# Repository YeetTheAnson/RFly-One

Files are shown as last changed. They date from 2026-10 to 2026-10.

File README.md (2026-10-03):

# RFly One

## Introduction
This project was inspired by [adsbee](https://github.com/PantsForBirds/adsbee) and [SoftRF](https://github.com/PantsForBirds/adsbee)!

This is the RFly One! This project was designed to be a fully offline general aviation proximity awareness system. The RFly One includes a custom ADS-B 1090MHz receiver frontend and support for FLARM AIR V7, OGNTP, FANET+ and more protocols, designed to keep pilots or enthusiasts aware of nearby manned or unmanned aerial vehicles without relying on an active internet connection.

The RFly One has a 2.4" TFT display to show nearby air traffic on an offline map (which can be loaded onto the SD card) or used as a flight insturment dashboard. It also has a BMI270 IMU and a MMC5983MA magnetometer to provide accurate heading, combined with an ATGM332D-5N31 GNSS module to show the current location on a map.

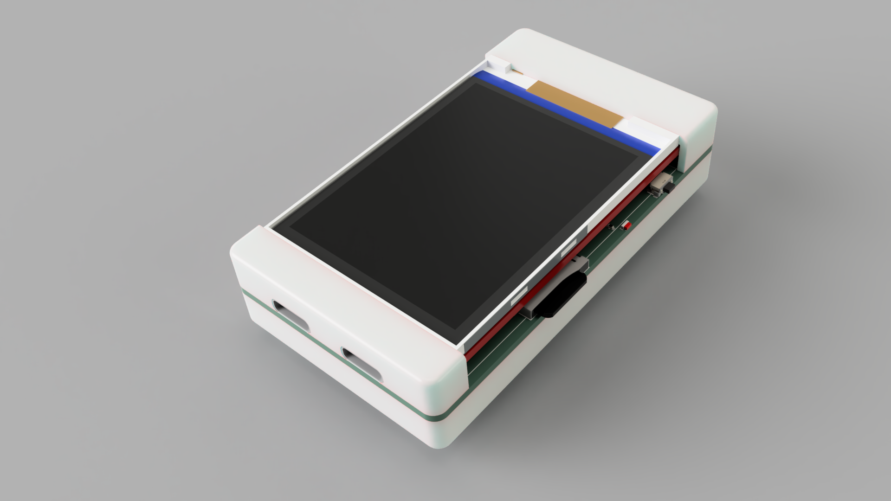
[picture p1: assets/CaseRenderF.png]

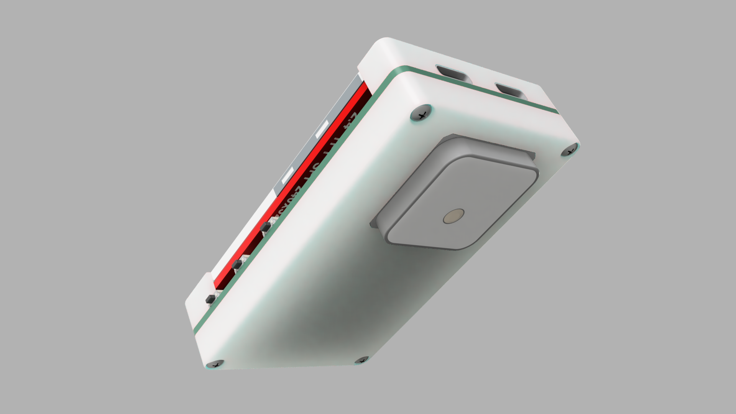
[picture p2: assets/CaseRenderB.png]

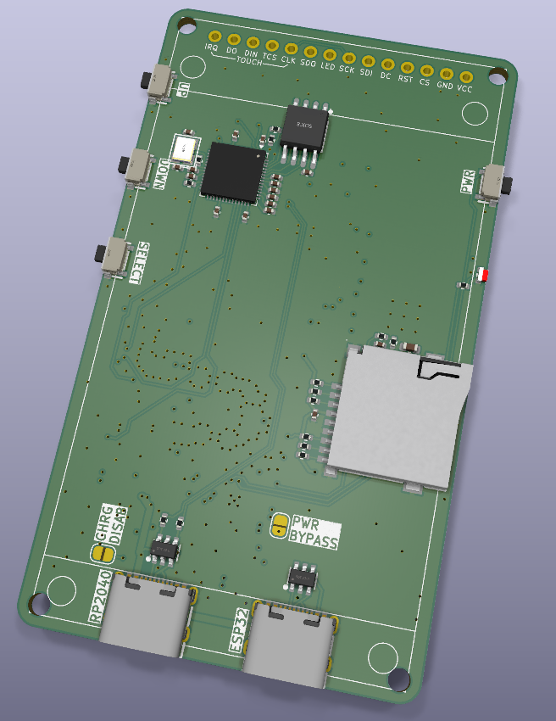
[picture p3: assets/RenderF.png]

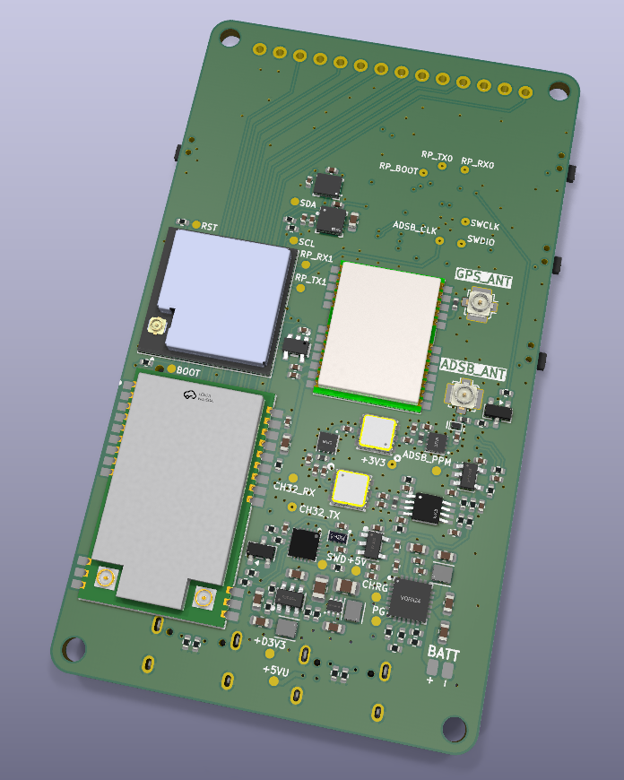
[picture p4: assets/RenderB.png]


## Specifications

### Features
* **Awareness Protocols:** ADS-B, FLARM AIR V7, OGNTP, FANET+, RemoteID
* **Positioning:** GNSS, Gyro, Accelerometer, Magnetometer
* **Storage:** MicroSD Card (For offline maps and flight logging)
* **Charging:** 2A Max

### Hardware
* **Main Processor** ESP32-S3
* **ADS-B Decoder:** RP2040
* **Button/Power Control:** CH32V003
* **GNSS:** ATGM332D-5N31
* **IMU:** BMI270
* **Magnetometer:** MMC5983MA
* **LoRa Radio:** E80-900M2212S (LR2021)
* **Display:** 2.4" TFT

## Pinout
| Feature | Pin name | ESP32 Pin | Description |
|---|---|---|---|
| **LCD** | `LCD_MOSI` | `GPIO 42` | SPI MOSI |
| | `LCD_MISO` | `GPIO 39` | SPI MISO |
| | `LCD_SCK` | `GPIO 41` | SPI Clock |
| | `LCD_CS` | `GPIO 44` | SPI Chip Select |
| | `LCD_LED` | `GPIO 40` | Backlight Control |
| | `LCD_CMD` | `GPIO 43` | LCD Command |
| **IMU** | `SDA` | `GPIO 36` | I2C Data |
| | `SCL` | `GPIO 35` | I2C Clock |
| **SD Card** | `SDIO_DAT0` | `GPIO 9` | Data 0 |
| | `SDIO_DAT1` | `GPIO 8` | Data 1 |
| | `SDIO_DAT2` | `GPIO 12` | Data 2 |
| | `SDIO_DAT3` | `GPIO 13` | Data 3 |
| | `SDIO_CMD` | `GPIO 11` | SD Command |
| | `SDIO_CD` | `GPIO 7` | SD Detect |
| | `SDIO_CLK` | `GPIO 10` | SD Clock |
| **LoRa Radio** | `LORA_MOSI` | `GPIO 2` | SPI MOSI |
| | `LORA_MISO` | `GPIO 1` | SPI MISO |
| | `LORA_SCK` | `GPIO 4` | SPI Clock |
| | `LORA_CE` | `GPIO 5` | SPI Chip Enable |
| | `LORA_BUSY` | `GPIO 16` | Radio Busy |
| **GNSS Module** | `GNSS_TX` | `GPIO 15` | UART RX |
| | `GNSS_RX` | `GPIO 14` | UART TX |
| | `PPS` | `GPIO 17` | GNSS Time |
| **Button/Power Control** | `CH32_TX` | `GPIO 21` | UART RX |
| | `CH32_RX` | `GPIO 18` | UART TX |
| | `BATT_ADC` | `GPIO 6` | ADC1 |
| **ADSB Decoder** | `RP_TX` | `GPIO 47` | UART RX |
| | `RP_RX` | `GPIO 48` | UART TX |
| | `ADSB_CLK` | `GPIO 34` | Extracted Clock From ADSB Signal |

----

## Hardware Overview
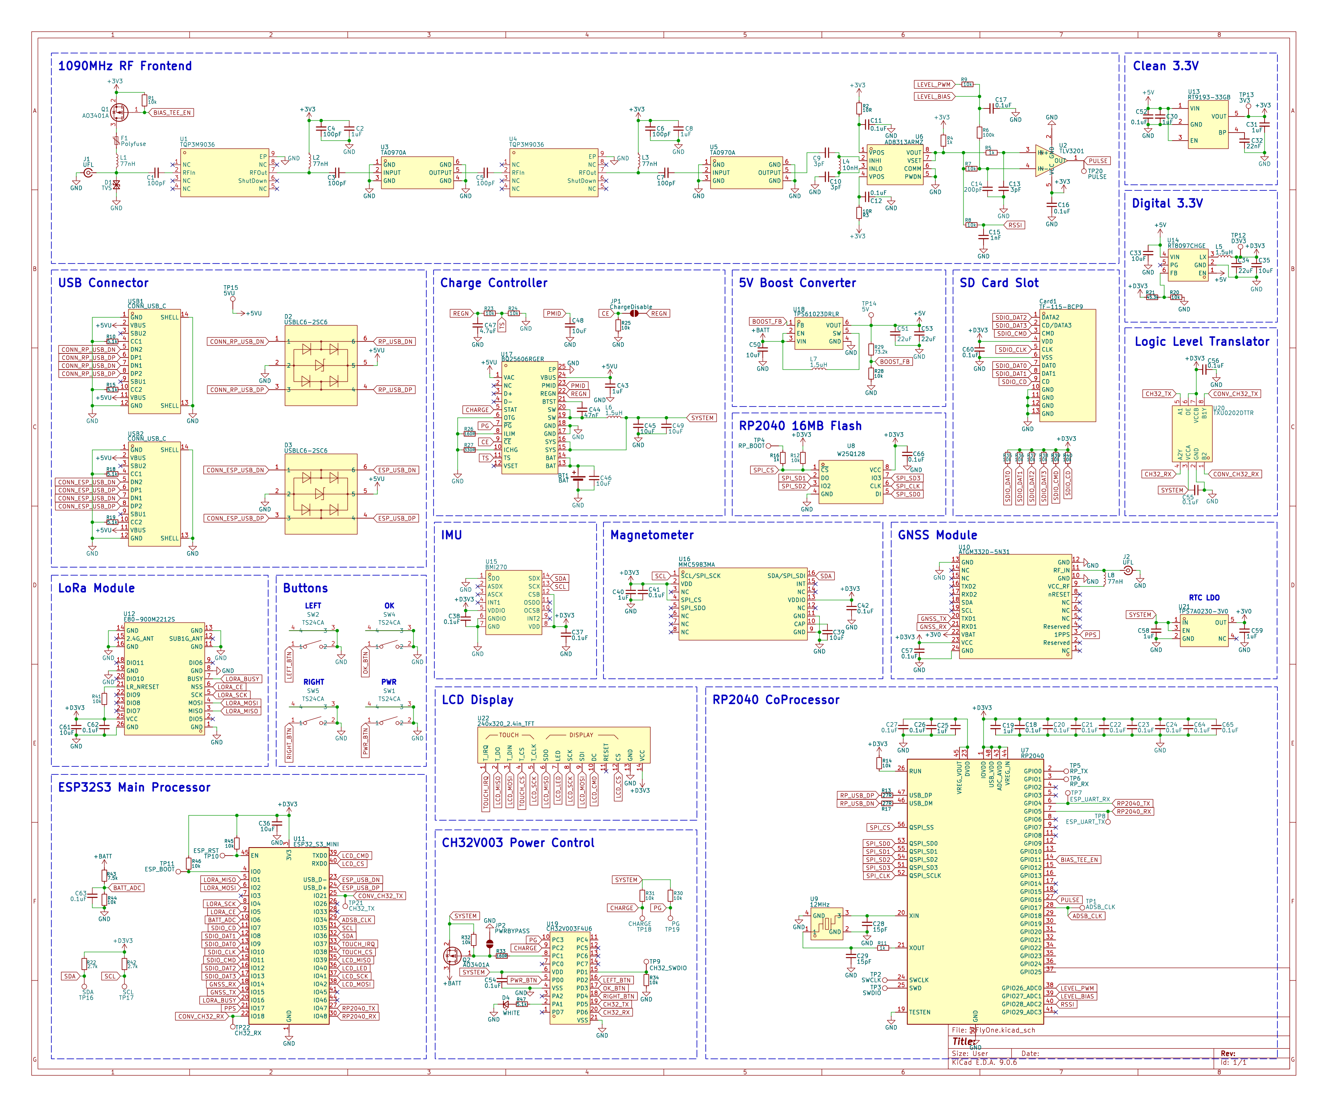
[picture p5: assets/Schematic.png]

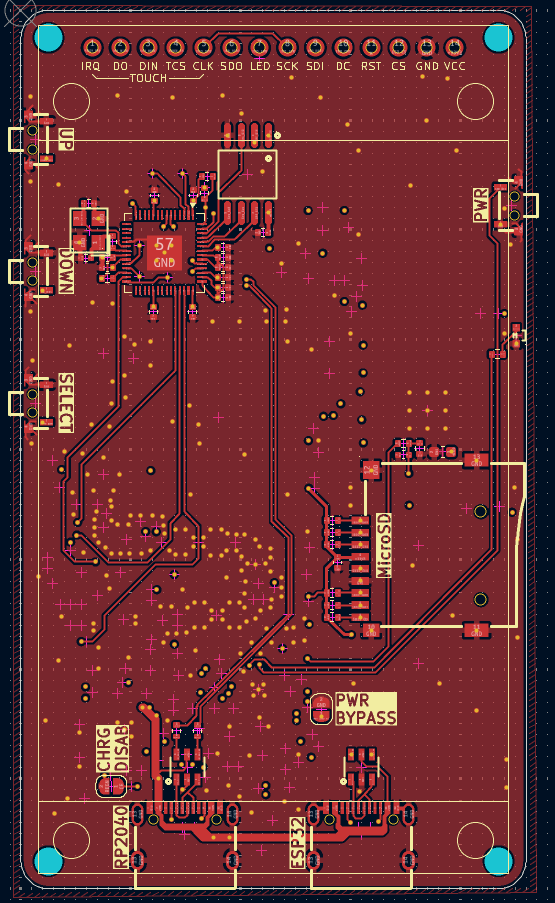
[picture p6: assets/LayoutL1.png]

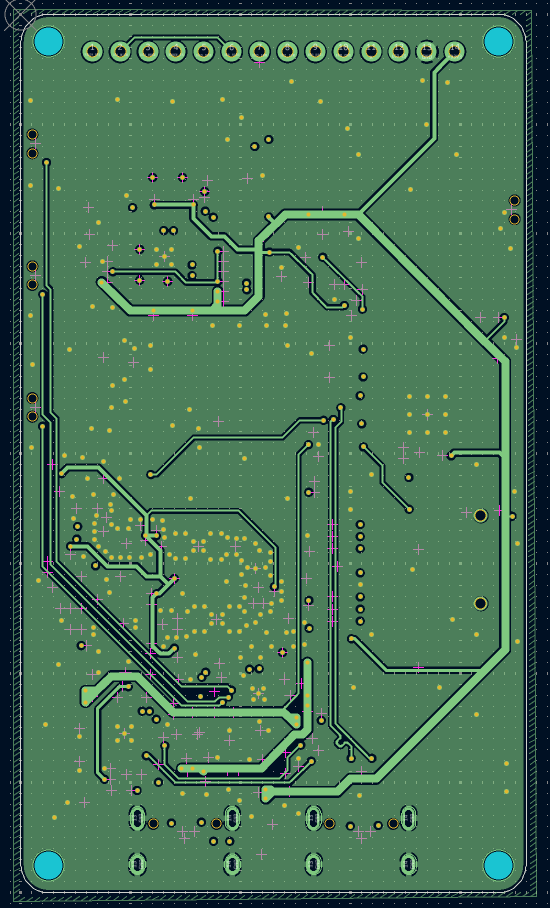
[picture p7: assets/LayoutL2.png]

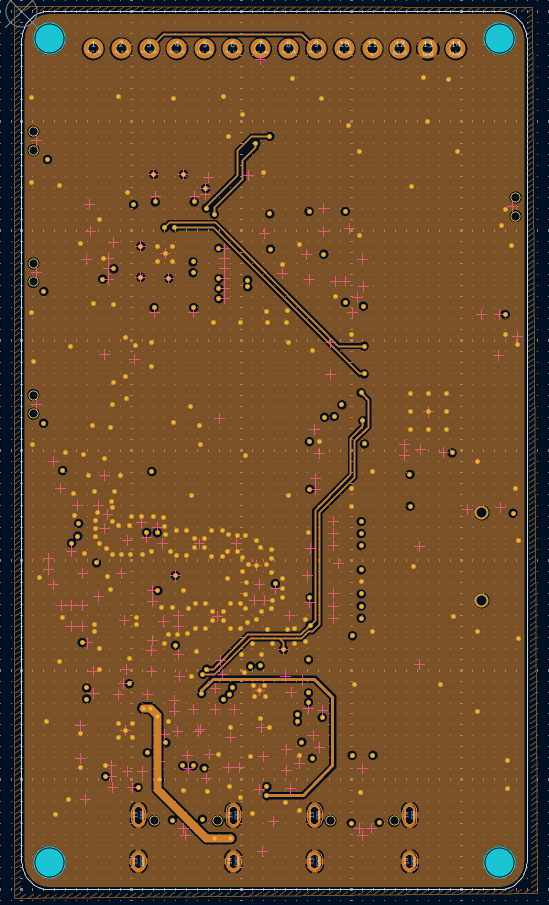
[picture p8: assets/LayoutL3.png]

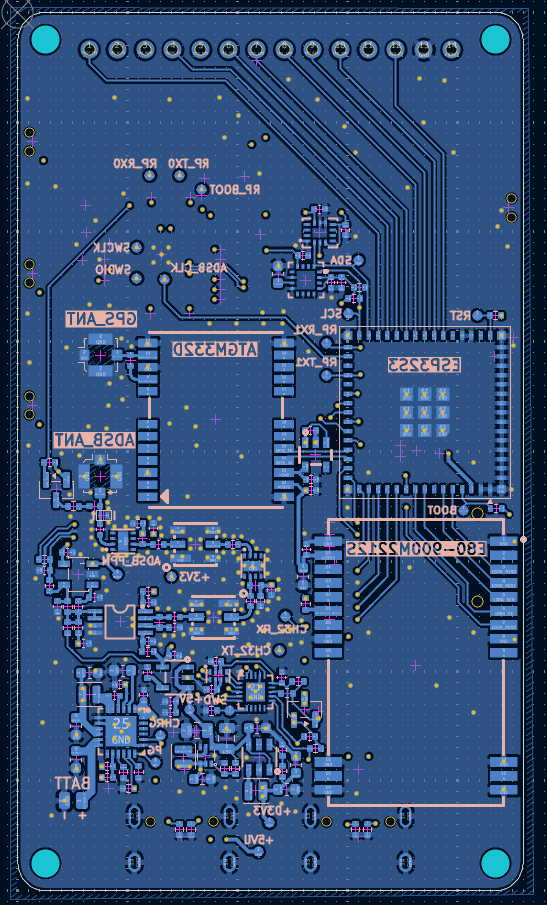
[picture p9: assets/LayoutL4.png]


----

## Firmware

### Building the RP2040 Firmware
1. Clone [this repository](https://github.com/YeetTheAnson/RFly-One) and enter the directory `cd RFly-One`
2. Open the `/firmware/source/rp2040.ino` file in ArduinoIDE
3. Paste `https://github.com/earlephilhower/arduino-pico/releases/download/global/package_rp2040_index.json` into `File > Preferences > Additional boards manager URLs`
4. Go to boards manager and install `Raspberry Pi Pico/RP2040/RP2350` by Earle F. Philhower, III
5. Click the upload button or `Sketch > Export Compiled Binary`

### Building the CH32V003 Firmware
1. Clone [this repository](https://github.com/YeetTheAnson/RFly-One) and enter the directory `cd RFly-One`
2. Open the `/firmware/source/ch32v003.ino` file in ArduinoIDE
3. Paste `https://alexandermandera.github.io/arduino-wch32v003/package_ch32v003_index.json` into `File > Preferences > Additional boards manager URLs`
4. Go to boards manager and install `WCH Boards` by Alexander Mandera
5. Click the upload button or `Sketch > Export Compiled Binary`

### Building the ESP32S3 Firmware
1. Clone [this repository](https://github.com/YeetTheAnson/RFly-One) and enter the directory `cd RFly-One`
2. Open the `/firmware/source/esp32.ino` file in ArduinoIDE
3. Paste `https://espressif.github.io/arduino-esp32/package_esp32_index.json` into `File > Preferences > Additional boards manager URLs`
4. Go to boards manager and install `ESP32` by Espressif
5. Click the upload button or `Sketch > Export Compiled Binary`

----

## Assembly

### Component List
* **Shell:**
    - [TopCase1.stl](https://github.com/YeetTheAnson/RFly-One/tree/main/production/3dPrint/TopCase1.stl)
    - [TopCase2.stl](https://github.com/YeetTheAnson/RFly-One/tree/main/production/3dPrint/TopCase2.stl)
    - [BottomCase.stl](https://github.com/YeetTheAnson/RFly-One/tree/main/production/3dPrint/BottomCase.stl)
* **PCB:**
    - [RFlyOne.zip](https://github.com/YeetTheAnson/RFly-One/tree/main/production/PCB/RFlyOne.zip)  
* **Fasteners:** 4x M2 10mm Self Tapping Screws
* **Battery:** Generic 500mAh LiPo battery (Size of battery is your choice)
* **SD Card:** Generic micro SD Card
* **Antennae:**
    - 2x 2400MHz FPC Antenna
    - 1x 1090MHz FPC Antenna
    - 1x 900MHz FPC Antenna
    - 1x Active GPS Ceramic Antenna

### Assembly Instructions
1. Slide the 3d printed parts `TopCase1.stl` and `TopCase2.stl` into place underneath the TFT LCD board.

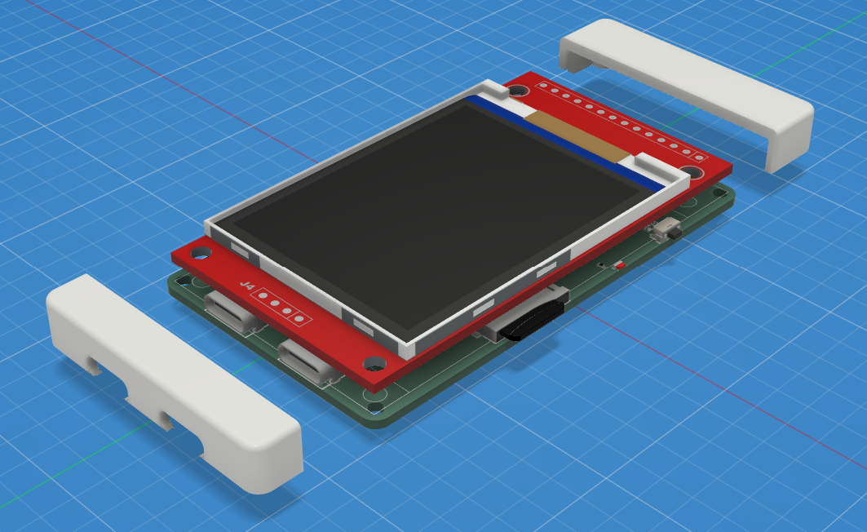
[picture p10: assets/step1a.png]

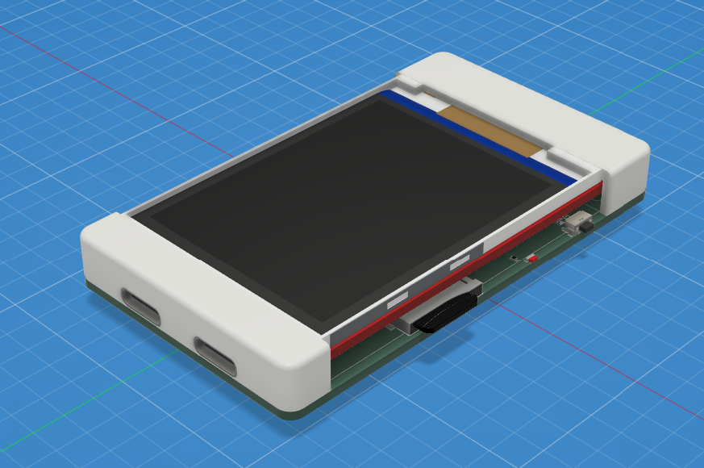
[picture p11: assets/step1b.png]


2. Attach the battery using double sided adhesives and solder the battery cable onto the dedicated pad. Then connect the 2.4GHz WiFi antenna, 2.4GHz LoRa antenna, 1090MHz ADSB antenna and 900MHz LoRa antenna, and secure the FPC antennae to `BottomCase.stl` using double sided adhesives.

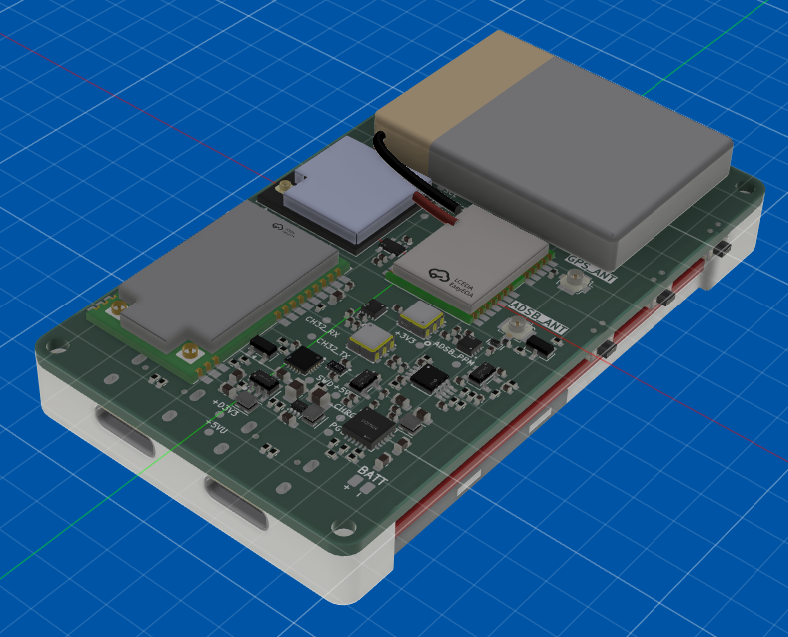
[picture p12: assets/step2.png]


3. Feed the GNSS antenana cable through the `BottomCase.stl` cutout and glue the antenna to the bottom case. Then connect the GNSS antenna connector to the PCB and close the case.

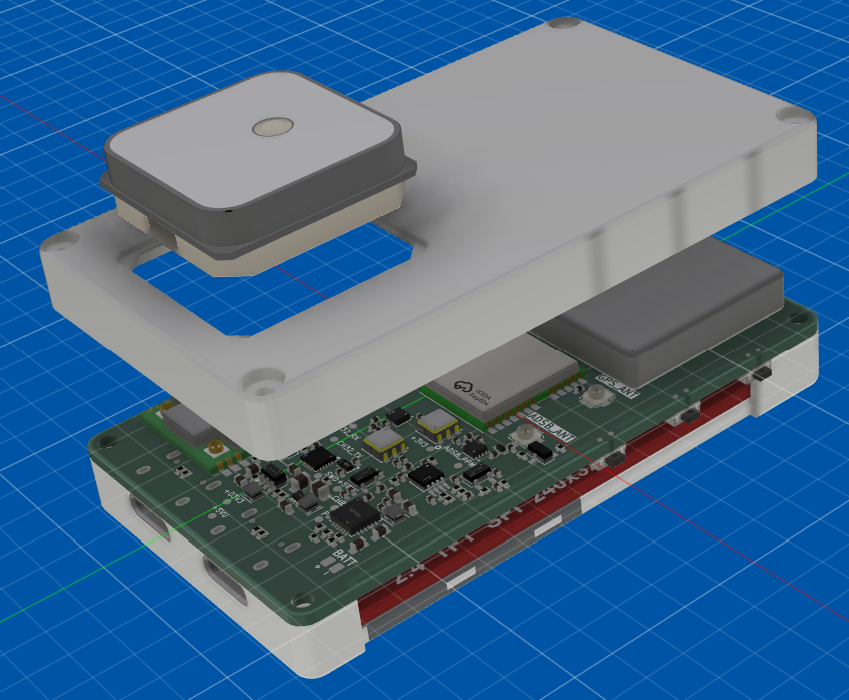
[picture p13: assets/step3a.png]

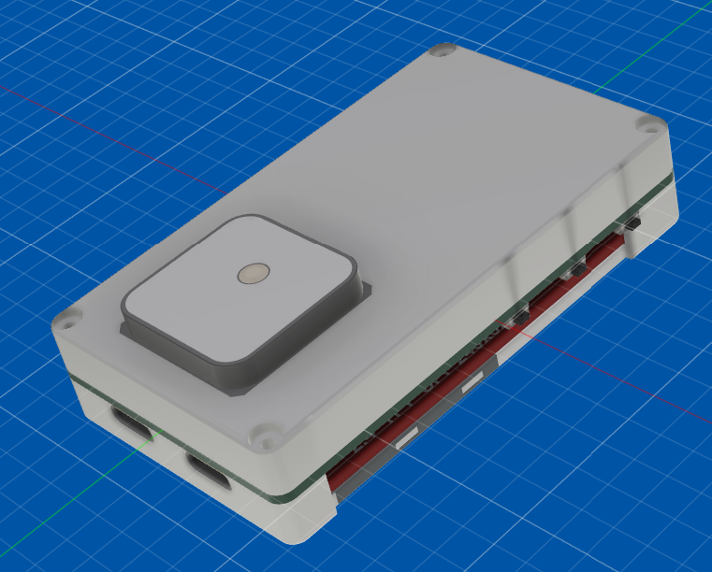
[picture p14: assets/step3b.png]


4. Secure the case using 4x M2 10mm Self Tapping Screws

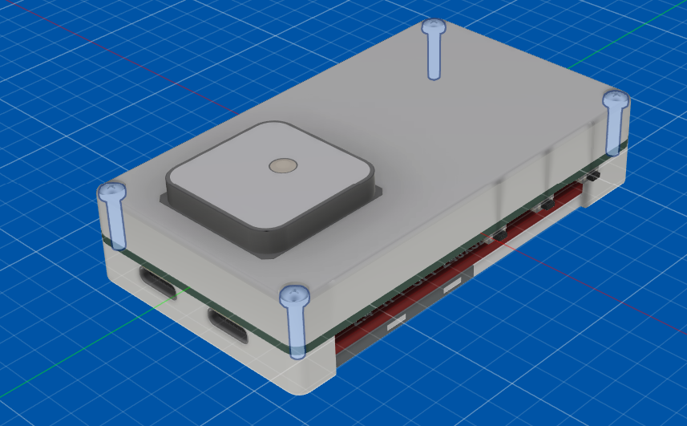
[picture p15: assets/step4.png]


----

## Bill of Material

| Category | Item Name | Description | Link | Vendor | Quantity | Total Price (USD) |
|---|---|---|---|---|---:|---:|
| PCB Components | CL10A106MA8NRNC | 10uF 0603 capacitor | [link](https://www.lcsc.com/product-detail/C96446.html) | LCSC | 20 | 1.52 |
| PCB Components | AO3401A | P channel MOSFET | [link](https://www.lcsc.com/product-detail/C15127.html) | LCSC | 5 | 0.51 |
| PCB Components | GRM1555C1H101JA01D | 100pF 0402 capacitor | [link](https://www.lcsc.com/product-detail/C77177.html) | LCSC | 50 | 0.55 |
| PCB Components | GJM1555C1H3R0BB01D | 3pF 0402 capacitor | [link](https://www.lcsc.com/product-detail/C88891.html) | LCSC | 50 | 0.86 |
| PCB Components | CC0402JRNPO9BN201 | 200pF 0402 capacitor | [link](https://www.lcsc.com/product-detail/C325462.html) | LCSC | 50 | 0.45 |
| PCB Components | CC0402KRX7R9BB102 | 1nF 0402 capacitor | [link](https://www.lcsc.com/product-detail/C106205.html) | LCSC | 100 | 0.23 |
| PCB Components | CC0402JRNPO9BN150 | 15pF 0402 capacitor | [link](https://www.lcsc.com/product-detail/C106997.html) | LCSC | 100 | 0.20 |
| PCB Components | CL21A226MOQNNNE | 22uF 0805 capacitor | [link](https://www.lcsc.com/product-detail/C98190.html) | LCSC | 10 | 1.06 |
| PCB Components | RClamp3361P-ES | 0.25pF DFN1006 TVS diode | [link](https://www.lcsc.com/product-detail/C22464622.html) | LCSC | 5 | 0.60 |
| PCB Components | 0402L020/6SR | 200mA 0402 PTC Fuse | [link](https://www.lcsc.com/product-detail/C53280164.html) | LCSC | 10 | 0.71 |
| PCB Components | LQW15CN77NJ10D | 77nH 0402 inductor | [link](https://www.lcsc.com/product-detail/C668466.html) | LCSC | 10 | 0.88 |
| PCB Components | LQG15HS10NJ02D | 10nH 0402 inductor | [link](https://www.lcsc.com/product-detail/C77103.html) | LCSC | 50 | 0.93 |
| PCB Components | RC0402FR-0727RL | 27R 0402 resistor | [link](https://www.lcsc.com/product-detail/C138021.html) | LCSC | 100 | 0.40 |
| PCB Components | RC0402FR-0745K3L | 45.3k 0402 resistor | [link](https://www.lcsc.com/product-detail/C137977.html) | LCSC | 100 | 0.17 |
| PCB Components | FRC0402F2701TS | 2.7k 0402 resistor | [link](https://www.lcsc.com/product-detail/C2909332.html) | LCSC | 100 | 0.19 |
| PCB Components | FRC0402F1600TS | 160R 0402 resistor | [link](https://www.lcsc.com/product-detail/C2933075.html) | LCSC | 100 | 0.18 |
| PCB Components | FRC0402F3300TS | 330R 0402 resistor | [link](https://www.lcsc.com/product-detail/C2930002.html) | LCSC | 100 | 0.22 |
| PCB Components | FRC0402F7322TS | 73.2k 0402 resistor | [link](https://www.lcsc.com/product-detail/C2998163.html) | LCSC | 100 | 0.19 |
| PCB Components | 0402WGF7501TCE | 7.5k 0402 resistor | [link](https://www.lcsc.com/product-detail/C25918.html) | LCSC | 100 | 0.22 |
| PCB Components | ABM8-272-T3 | 12MHz 10pF 3225 crystal | [link](https://www.lcsc.com/product-detail/C20625731.html) | LCSC | 1 | 0.63 |
| PCB Components | ATGM332D-5N31 | GNSS module | [link](https://www.lcsc.com/product-detail/C128659.html) | LCSC | 1 | 3.58 |
| PCB Components | BMI270 | IMU | [link](https://www.lcsc.com/product-detail/C2836813.html) | LCSC | 2 | 5.75 |
| PCB Components | BQ25606RGER | Battery charge controller | [link](https://www.lcsc.com/product-detail/C374063.html) | LCSC | 1 | 1.64 |
| PCB Components | MMC5983MA | Magnetometer | [link](https://www.lcsc.com/product-detail/C404329.html) | LCSC | 1 | 2.28 |
| PCB Components | RT9193-33GB | 3.3V LDO regulator | [link](https://www.lcsc.com/product-detail/C15651.html) | LCSC | 5 | 0.69 |
| PCB Components | TA0970A | 1090MHz SAW filter | [link](https://www.lcsc.com/product-detail/C7115531.html) | LCSC | 2 | 3.09 |
| PCB Components | TLV3201AIDBVR | Comparator | [link](https://www.lcsc.com/product-detail/C105188.html) | LCSC | 1 | 0.98 |
| PCB Components | TPS61023DRLR | Boost converter | [link](https://www.lcsc.com/product-detail/C919459.html) | LCSC | 5 | 1.24 |
| PCB Components | TPS7A0230PDBVR | ULC 3V LDO regulator | [link](https://www.lcsc.com/product-detail/C3747031.html) | LCSC | 1 | 0.45 |
| PCB Components | TQP3M9036 | LNA | [link](https://www.lcsc.com/product-detail/C920261.html) | LCSC | 2 | 6.29 |
| PCB Components | TXU0202DTTR | Logic level translator | [link](https://www.lcsc.com/product-detail/C18197534.html) | LCSC | 2 | 1.62 |
| PCB Components | W25Q128JVSIQ | 128Mb 16MB NOR flash | [link](https://www.lcsc.com/product-detail/C97521.html) | LCSC | 1 | 2.58 |
| PCB Components | ESP32-S3-MINI-1U-N4R2 | Main processor | [link](https://www.lcsc.com/product-detail/C22356044.html) | LCSC | 1 | 4.61 |
| PCB Components | RP2040 | ADSB decoder coprocessor | [link](https://www.lcsc.com/product-detail/C2040.html) | LCSC | 1 | 1.00 |
| PCB Components | LCSC Shipping | 4PX | - | LCSC | 1 | 4.71 |
| PCB | PCB | 4 layer bare PCB | - | JLCPCB | 1 | 8.00 |
| PCB | JLCPCB Shipping | E-POST | - | JLCPCB | 1 | 5.78 |
| PCB Components | E80-900M2213S | LR2021 LoRA module | [link](https://www.aliexpress.com/item/1005012863308600.html) | AliExpress | 1 | 8.69 |
| PCB Components | AD8313ARMZ | RF logarithmic power detector | [link](https://www.aliexpress.com/item/1005009749065916.html) | AliExpress | 1 | 3.31 |
| PCB Components | AliExpress Shipping | AliExpress Shipping | - | AliExpress | 1 | 5.79 |
| Parts | 2.4" TFT LCD | 2.4" TFT LCD | [link](https://shopee.com.my/TFT-Display-0.96-1.3-1.44-1.77-1.8-2.4-2.8-inch-IPS-7P-SPI-HD-65K-TFT-Full-Color-LCD-Module-ST7735-Drive-IC-80*160-For-Arduino-i.299149454.2147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) | Shopee | 1 | 4.35 |
| Parts | UWB 700-2700MHz antenna large | For 1090MHz ADSB receiver | [link](https://shopee.com.my/Gsm-3G-4G-LTE-5G-nb-iot-iot-Module-Signal-Enhancement-FPC-PCB-Built-in-Patch-Antenna-i.419312080.27871596372) | Shopee | 1 | 0.70 |
| Parts | UWB 700-2700MHz antenna small | For 900MHz LoRa transceiver | [link](https://shopee.com.my/Gsm-3G-4G-LTE-5G-nb-iot-iot-Module-Signal-Enhancement-FPC-PCB-Built-in-Patch-Antenna-i.419312080.27871596373) | Shopee | 1 | 0.65 |
| Parts | 2.4GHz antenna | For ESP32 WiFi/BT and LoRa | [link](https://shopee.com.my/2.4g-5g-5.8g-Dual-Band-Antenna-Built-in-FPC-Soft-Board-Antenna-wifi-Bluetooth-PCB-Patch-ipex-Antenna-i.419312080.27171149912) | Shopee | 2 | 0.95 |
| Parts | Shopee Shipping | SPX Express | - | Shopee | 2 | 2.60 |

- **PCB Components Total:** $69.00
- **PCB Total:** $13.78
- **Parts Total:** $9.25
### **Grand Total:** $92.03

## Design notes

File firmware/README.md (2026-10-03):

> [!CAUTION]
> The current firmware is for validation only, and cannnot decode ADS-B signal yet

### ESP32S3
- Initialize 2.4" display and display test results
- Test and return BMI270 IMU & MMC5983 magnetometer raw values
- Test and initialize E80-900M2212S LoRa module
- Test and initialize ATGM332D-5N31 GNSS module
- Test whether CH32V003 can be reached with serial loopback
- Test whether RP2040 can be reached with serial loopback
- Measure frequency of RP2040 ADS-B extracted clock
- Test if SD card can be detected and accessed

### RP2040
- Extract and output a clock signal from ADSB PPM signal with manchester encoding
- Relay serial data

### Ch32V003
- Blink LED
- Power button toggle power on and off to the rest of the system
- Relay serial data
- Send button state over serial

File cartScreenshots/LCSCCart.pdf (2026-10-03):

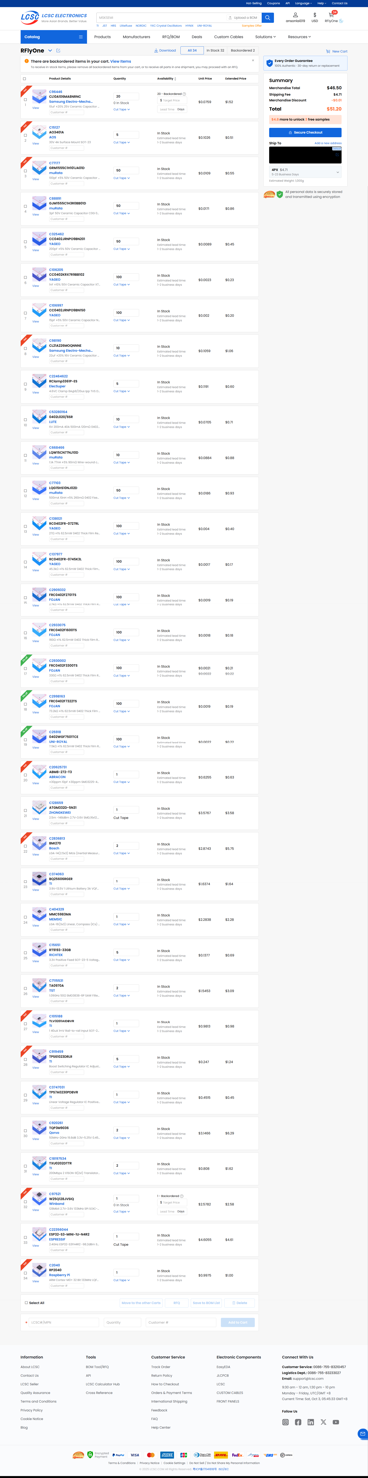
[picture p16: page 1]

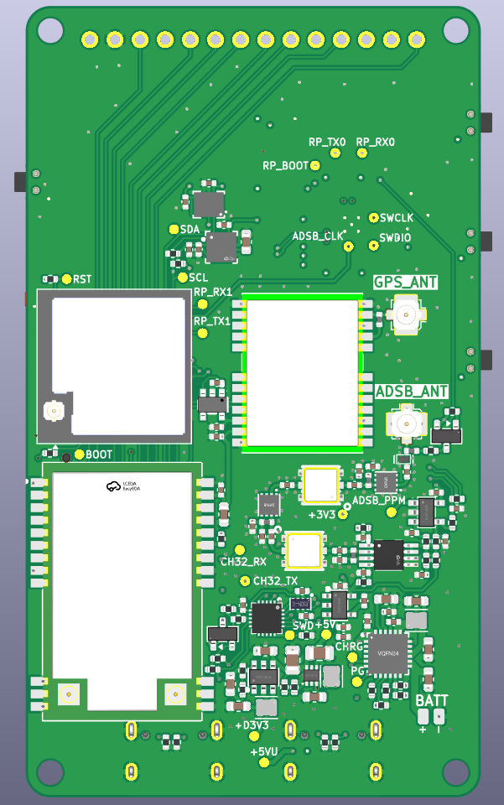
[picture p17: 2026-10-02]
assets/FlatRenderB.png

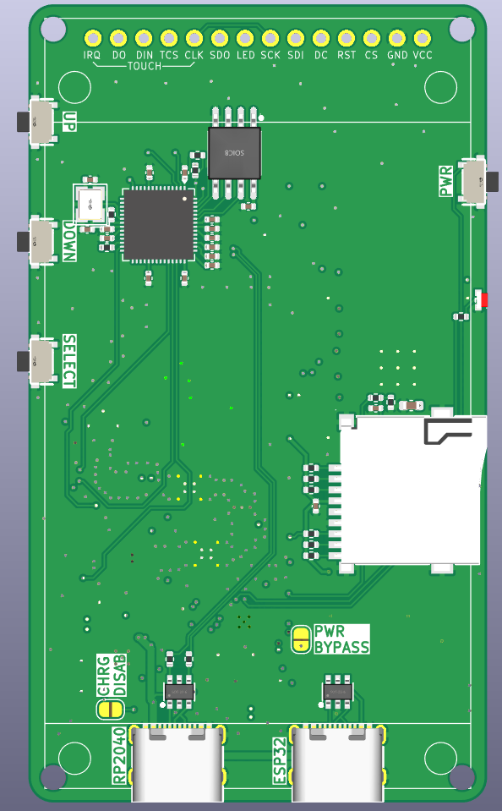
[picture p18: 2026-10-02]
assets/FlatRenderF.png

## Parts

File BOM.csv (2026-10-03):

Category | Item Name | Description | Link | Vendor | Quantity | Total Price (USD)
PCB Components | CL10A106MA8NRNC | 10uF 0603 capacitor | https://www.lcsc.com/product-detail/C96446.html | LCSC | 20 | 1.52
PCB Components | AO3401A | P channel MOSFET | https://www.lcsc.com/product-detail/C15127.html | LCSC | 5 | 0.51
PCB Components | GRM1555C1H101JA01D | 100pF 0402 capacitor | https://www.lcsc.com/product-detail/C77177.html | LCSC | 50 | 0.55
PCB Components | GJM1555C1H3R0BB01D | 3pF 0402 capacitor | https://www.lcsc.com/product-detail/C88891.html | LCSC | 50 | 0.86
PCB Components | CC0402JRNPO9BN201 | 200pF 0402 capacitor | https://www.lcsc.com/product-detail/C325462.html | LCSC | 50 | 0.45
PCB Components | CC0402KRX7R9BB102 | 1nF 0402 capacitor | https://www.lcsc.com/product-detail/C106205.html | LCSC | 100 | 0.23
PCB Components | CC0402JRNPO9BN150 | 15pF 0402 capacitor | https://www.lcsc.com/product-detail/C106997.html | LCSC | 100 | 0.20
PCB Components | CL21A226MOQNNNE | 22uF 0805 capacitor | https://www.lcsc.com/product-detail/C98190.html | LCSC | 10 | 1.06
PCB Components | RClamp3361P-ES | 0.25pF DFN1006 TVS diode | https://www.lcsc.com/product-detail/C22464622.html | LCSC | 5 | 0.60
PCB Components | 0402L020/6SR | 200mA 0402 PTC Fuse | https://www.lcsc.com/product-detail/C53280164.html | LCSC | 10 | 0.71
PCB Components | LQW15CN77NJ10D | 77nH 0402 inductor | https://www.lcsc.com/product-detail/C668466.html | LCSC | 10 | 0.88
PCB Components | LQG15HS10NJ02D | 10nH 0402 inductor | https://www.lcsc.com/product-detail/C77103.html | LCSC | 50 | 0.93
PCB Components | RC0402FR-0727RL | 27R 0402 resistor | https://www.lcsc.com/product-detail/C138021.html | LCSC | 100 | 0.40
PCB Components | RC0402FR-0745K3L | 45.3k 0402 resistor | https://www.lcsc.com/product-detail/C137977.html | LCSC | 100 | 0.17
PCB Components | FRC0402F2701TS | 2.7k 0402 resistor | https://www.lcsc.com/product-detail/C2909332.html | LCSC | 100 | 0.19
PCB Components | FRC0402F1600TS | 160R 0402 resistor | https://www.lcsc.com/product-detail/C2933075.html | LCSC | 100 | 0.18
PCB Components | FRC0402F3300TS | 330R 0402 resistor | https://www.lcsc.com/product-detail/C2930002.html | LCSC | 100 | 0.22
PCB Components | FRC0402F7322TS | 73.2k 0402 resistor | https://www.lcsc.com/product-detail/C2998163.html | LCSC | 100 | 0.19
PCB Components | 0402WGF7501TCE | 7.5k 0402 resistor | https://www.lcsc.com/product-detail/C25918.html | LCSC | 100 | 0.22
PCB Components | ABM8-272-T3 | 12MHz 10pF 3225 crystal | https://www.lcsc.com/product-detail/C20625731.html | LCSC | 1 | 0.63
PCB Components | ATGM332D-5N31 | GNSS module | https://www.lcsc.com/product-detail/C128659.html | LCSC | 1 | 3.58
PCB Components | BMI270 | IMU | https://www.lcsc.com/product-detail/C2836813.html | LCSC | 2 | 5.75
PCB Components | BQ25606RGER | Battery charge controller | https://www.lcsc.com/product-detail/C374063.html | LCSC | 1 | 1.64
PCB Components | MMC5983MA | Magnetometer | https://www.lcsc.com/product-detail/C404329.html | LCSC | 1 | 2.28
PCB Components | RT9193-33GB | 3.3V LDO regulator | https://www.lcsc.com/product-detail/C15651.html | LCSC | 5 | 0.69
PCB Components | TA0970A | 1090MHz SAW filter | https://www.lcsc.com/product-detail/C7115531.html | LCSC | 2 | 3.09
PCB Components | TLV3201AIDBVR | Comparator | https://www.lcsc.com/product-detail/C105188.html | LCSC | 1 | 0.98
PCB Components | TPS61023DRLR | Boost converter | https://www.lcsc.com/product-detail/C919459.html | LCSC | 5 | 1.24
PCB Components | TPS7A0230PDBVR | ULC 3V LDO regulator | https://www.lcsc.com/product-detail/C3747031.html | LCSC | 1 | 0.45
PCB Components | TQP3M9036 | LNA | https://www.lcsc.com/product-detail/C920261.html | LCSC | 2 | 6.29
PCB Components | TXU0202DTTR | Logic level translator | https://www.lcsc.com/product-detail/C18197534.html | LCSC | 2 | 1.62
PCB Components | W25Q128JVSIQ | 128Mb 16MB NOR flash | https://www.lcsc.com/product-detail/C97521.html | LCSC | 1 | 2.58
PCB Components | ESP32-S3-MINI-1U-N4R2 | Main processor | https://www.lcsc.com/product-detail/C22356044.html | LCSC | 1 | 4.61
PCB Components | RP2040 | ADSB decoder coprocessor | https://www.lcsc.com/product-detail/C2040.html | LCSC | 1 | 1.00
PCB Components | LCSC Shipping | 4PX | - | LCSC | 1 | 4.71
PCB | PCB | 4 layer bare PCB | - | JLCPCB | 1 | 8.00
PCB | JLCPCB Shipping | E-POST | - | JLCPCB | 1 | 5.78
PCB Components | E80-900M2213S | LR2021 LoRA module | https://www.aliexpress.com/item/1005012863308600.html | AliExpress | 1 | 8.69
PCB Components | AD8313ARMZ | RF logarithmic power detector | https://www.aliexpress.com/item/1005009749065916.html | AliExpress | 1 | 3.31
PCB Components | AliExpress Shipping | AliExpress Shipping | - | AliExpress | 1 | 5.79
Parts | 2.4" TFT LCD | 2.4" TFT LCD | https://shopee.com.my/TFT-Display-0.96-1.3-1.44-1.77-1.8-2.4-2.8-inch-IPS-7P-SPI-HD-65K-TFT-Full-Color-LCD-Module-ST7735-Drive-IC-80*160-For-Arduino-i.2991494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 | Shopee | 1 | 4.35
Parts | UWB 700-2700MHz antenna large | For 1090MHz ADSB receiver | https://shopee.com.my/Gsm-3G-4G-LTE-5G-nb-iot-iot-Module-Signal-Enhancement-FPC-PCB-Built-in-Patch-Antenna-i.419312080.27871596372 | Shopee | 1 | 0.70
Parts | UWB 700-2700MHz antenna small | For 900MHz LoRa transceiver | https://shopee.com.my/Gsm-3G-4G-LTE-5G-nb-iot-iot-Module-Signal-Enhancement-FPC-PCB-Built-in-Patch-Antenna-i.419312080.27871596373 | Shopee | 1 | 0.65
Parts | 2.4GHz antenna | For ESP32 WiFi/BT and LoRa | https://shopee.com.my/2.4g-5g-5.8g-Dual-Band-Antenna-Built-in-FPC-Soft-Board-Antenna-wifi-Bluetooth-PCB-Patch-ipex-Antenna-i.419312080.27171149912 | Shopee | 2 | 0.95
Parts | Shopee Shipping | SPX Express | - | Shopee | 2 | 2.60
Grand Total | 92.03

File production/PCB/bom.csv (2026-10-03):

Designator | Footprint | Quantity | Value | LCSC Part #
C1, C3, C4, C5, C6, C7 | 0402 | 6 | 100pF | C77177
C10, C13, C9 | 0402 | 3 | 3pF | C88891
C11, C12, C16, C17, C18, C20, C21, C22, C23, C24, C26, C27, C37, C38, C41, C42, C52, C54, C55, C56, C57, C60, C62, C63, C64, C65, C66 | 0402 | 27 | 0.1uF | C307331
C14 | 0402 | 1 | 200pF | C325462
C15 | 0402 | 1 | 1nF | C106205
C19, C2, C25, C30, C31, C40, C43, C58, C59, C8 | 0402 | 10 | 1uF | C52923
C28, C29 | 0402 | 2 | 15pF | C106997
C32 | 0402 | 1 | 22nF | C1532
C33, C35, C36, C39, C45, C46, C48, C49, C50, C61 | 0603 | 10 | 10uF | C96446
C34 | 0603 | 1 | 22uF | C59461
C44 | 0402 | 1 | 47nF | C272875
C47 | 0402 | 1 | 4.7uF | C23733
C51, C53 | 0805 | 2 | 22uF | C98190
CARD1 | TF-SMD_TF-115-BCP9 | 1 | TF-115-BCP9 | C720505
D1 | DFN-2_L1.0-W0.6-P0.65-BI | 1 | TVS | C22464622
D2, D3 | SOT-23-6_L2.9-W1.6-P0.95-LS2.8-BL | 2 | USBLC6-2SC6 | C7519
D4 | LED-SMD_L1.6-W1.1-R-RD_WHITE | 1 | WHITE | C46635136
F1 | 0402 | 1 | Polyfuse | C53280164
J1, J2 | UFL | 2 | UFL | C5137195
L1, L2, L3, L8 | 0402 | 4 | 77nH | C668466
L4 | 0402 | 1 | 10nH | C77103
L5, L6, L7 | L_Changjiang_FTC201610S | 3 | 1.5uH | C5832343
Q1, Q2 | SOT-23 | 2 | AO3401A | C15127
R1, R12, R14, R20, R23, R24, R25, R28, R30, R31, R32, R34, R35, R36, R37, R38, R39, R40, R41, R44, R45, R46, R7, R8, R9 | 0402 | 25 | 10k | C25744
R10, R15, R18, R19, R47 | 0402 | 5 | 5.1k | C25905
R11, R16, R4, R5 | 0402 | 4 | 1k | C11702
R13, R17 | 0402 | 2 | 27R | C138021
R2, R3 | 0402 | 2 | 10R | C25077
R21 | 0402 | 1 | 45.3k | C137977
R22, R42 | 0402 | 2 | 2.7k | C2909332
R26, R33 | 0402 | 2 | 160R | C2933075
R27 | 0402 | 1 | 330R | C2930002
R29 | 0402 | 1 | 73.2k | C2998163
R43 | 0402 | 1 | 7.5k | C25918
R6 | 0402 | 1 | 100k | C25741
SW1, SW2, SW4, SW5 | SW-SMD_2P-TS24CA | 4 | TS24CA | C393942
U1, U4 | DFN-8_L2.0-W2.0-P0.50-BL-EP | 2 | TQP3M9036 | C920261
U10 | GSM-SMD_ATGM332D-5N31 | 1 | ATGM332D-5N31 | C128659
U11 | ESP32-S2-MINI-1U | 1 | ESP32_S3_MINI | C22356044
U12 | WIRELM-SMD_E80-900M2212S | 1 | E80-900M2212S | C55338904
U13 | SOT-23-5_L3.0-W1.7-P0.95-LS2.8-BL | 1 | RT9193-33GB | C15651
U14 | SOT-23-6_L2.9-W1.6-P0.95-LS2.8-BL | 1 | RT8097CHGE | C3031673
U15 | LGA-14_L3.0-W2.5-P0.50-BR | 1 | BMI270 | C2836813
U16 | LGA-16_L3.0-W3.0-P0.50-BL_SQ | 1 | MMC5983MA | C404329
U17 | VQFN-24_L4.0-W4.0-P0.50-TL-EP2.8 | 1 | BQ25606RGER | C374063
U18 | SOT-563_L1.6-W1.2-P0.50-LS1.6-BR | 1 | TPS61023DRLR | C919459
U19 | QFN-20_L3.0-W3.0-P0.40-TL-EP1.7 | 1 | CH32V003F4U6 | C5299908
U2 | SOT-23-5_L3.0-W1.7-P0.95-LS2.8-BR | 1 | TLV3201 | C105188
U20 | XSON-8_L2.0-W1.0-P0.50-BL | 1 | TXU0202DTTR | C18197534
U21 | SOT-23-5_L2.9-W1.6-P0.95-LS2.8-BR | 1 | TPS7A0230-3V0 | C3747031
U3, U5 | FILTER-SMD_6P-L3.8-W3.8-BL | 2 | TA0970A | C7115531
U6 | MSOP-8_L3.0-W3.0-P0.65-LS4.9-BL | 1 | AD8313ARMZ | C578690
U7 | QFN-56-1EP_7x7mm_P0.4mm_EP3.2x3.2mm | 1 | RP2040 | C2040
U8 | SOIC-8_L5.3-W5.3-P1.27-LS8.0-BL | 1 | W25Q128 | C97521
U9 | CRYSTAL-SMD_4P-L3.2-W2.5-BL | 1 | 12MHz | C20625731
USB1, USB2 | USB-C-SMD_TYPE-C-6PIN-2MD-073 | 2 | CONN_USB_C | C2765186

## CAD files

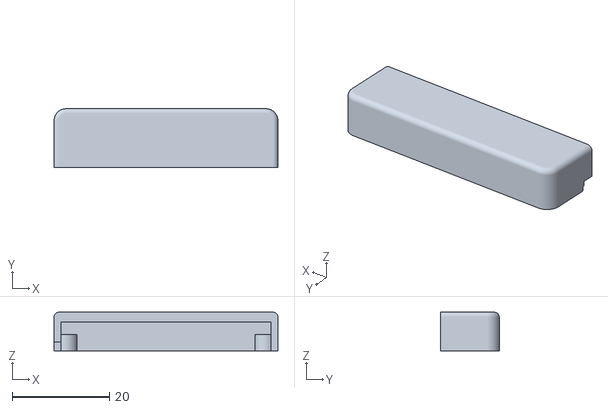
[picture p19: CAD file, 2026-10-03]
production/3dPrint/TopCase2.stl
46.0 x 12.0 x 7.93

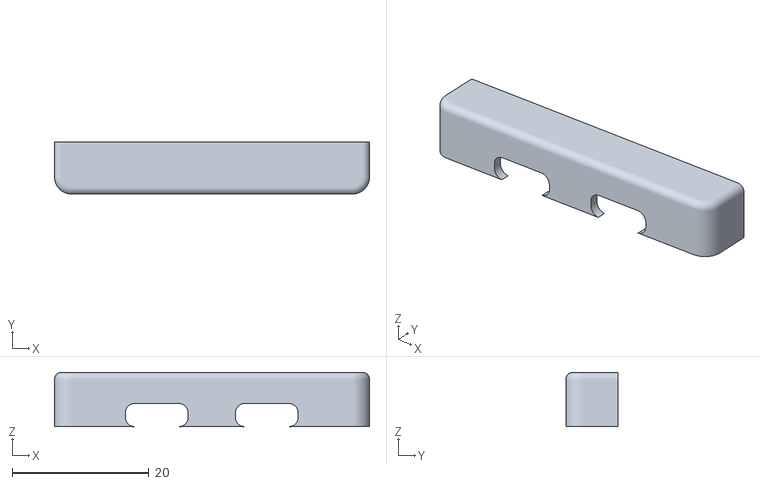
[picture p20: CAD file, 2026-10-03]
production/3dPrint/TopCase1.stl
46.0 x 7.62 x 7.93

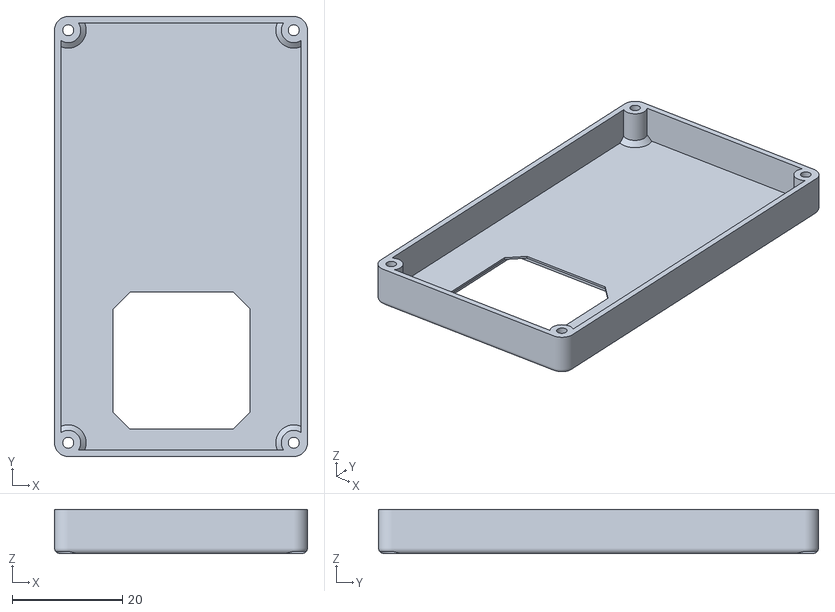
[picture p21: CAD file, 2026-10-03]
production/3dPrint/BottomCase.stl
46.0 x 80.0 x 8.00

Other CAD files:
CAD/Assembled.f3z

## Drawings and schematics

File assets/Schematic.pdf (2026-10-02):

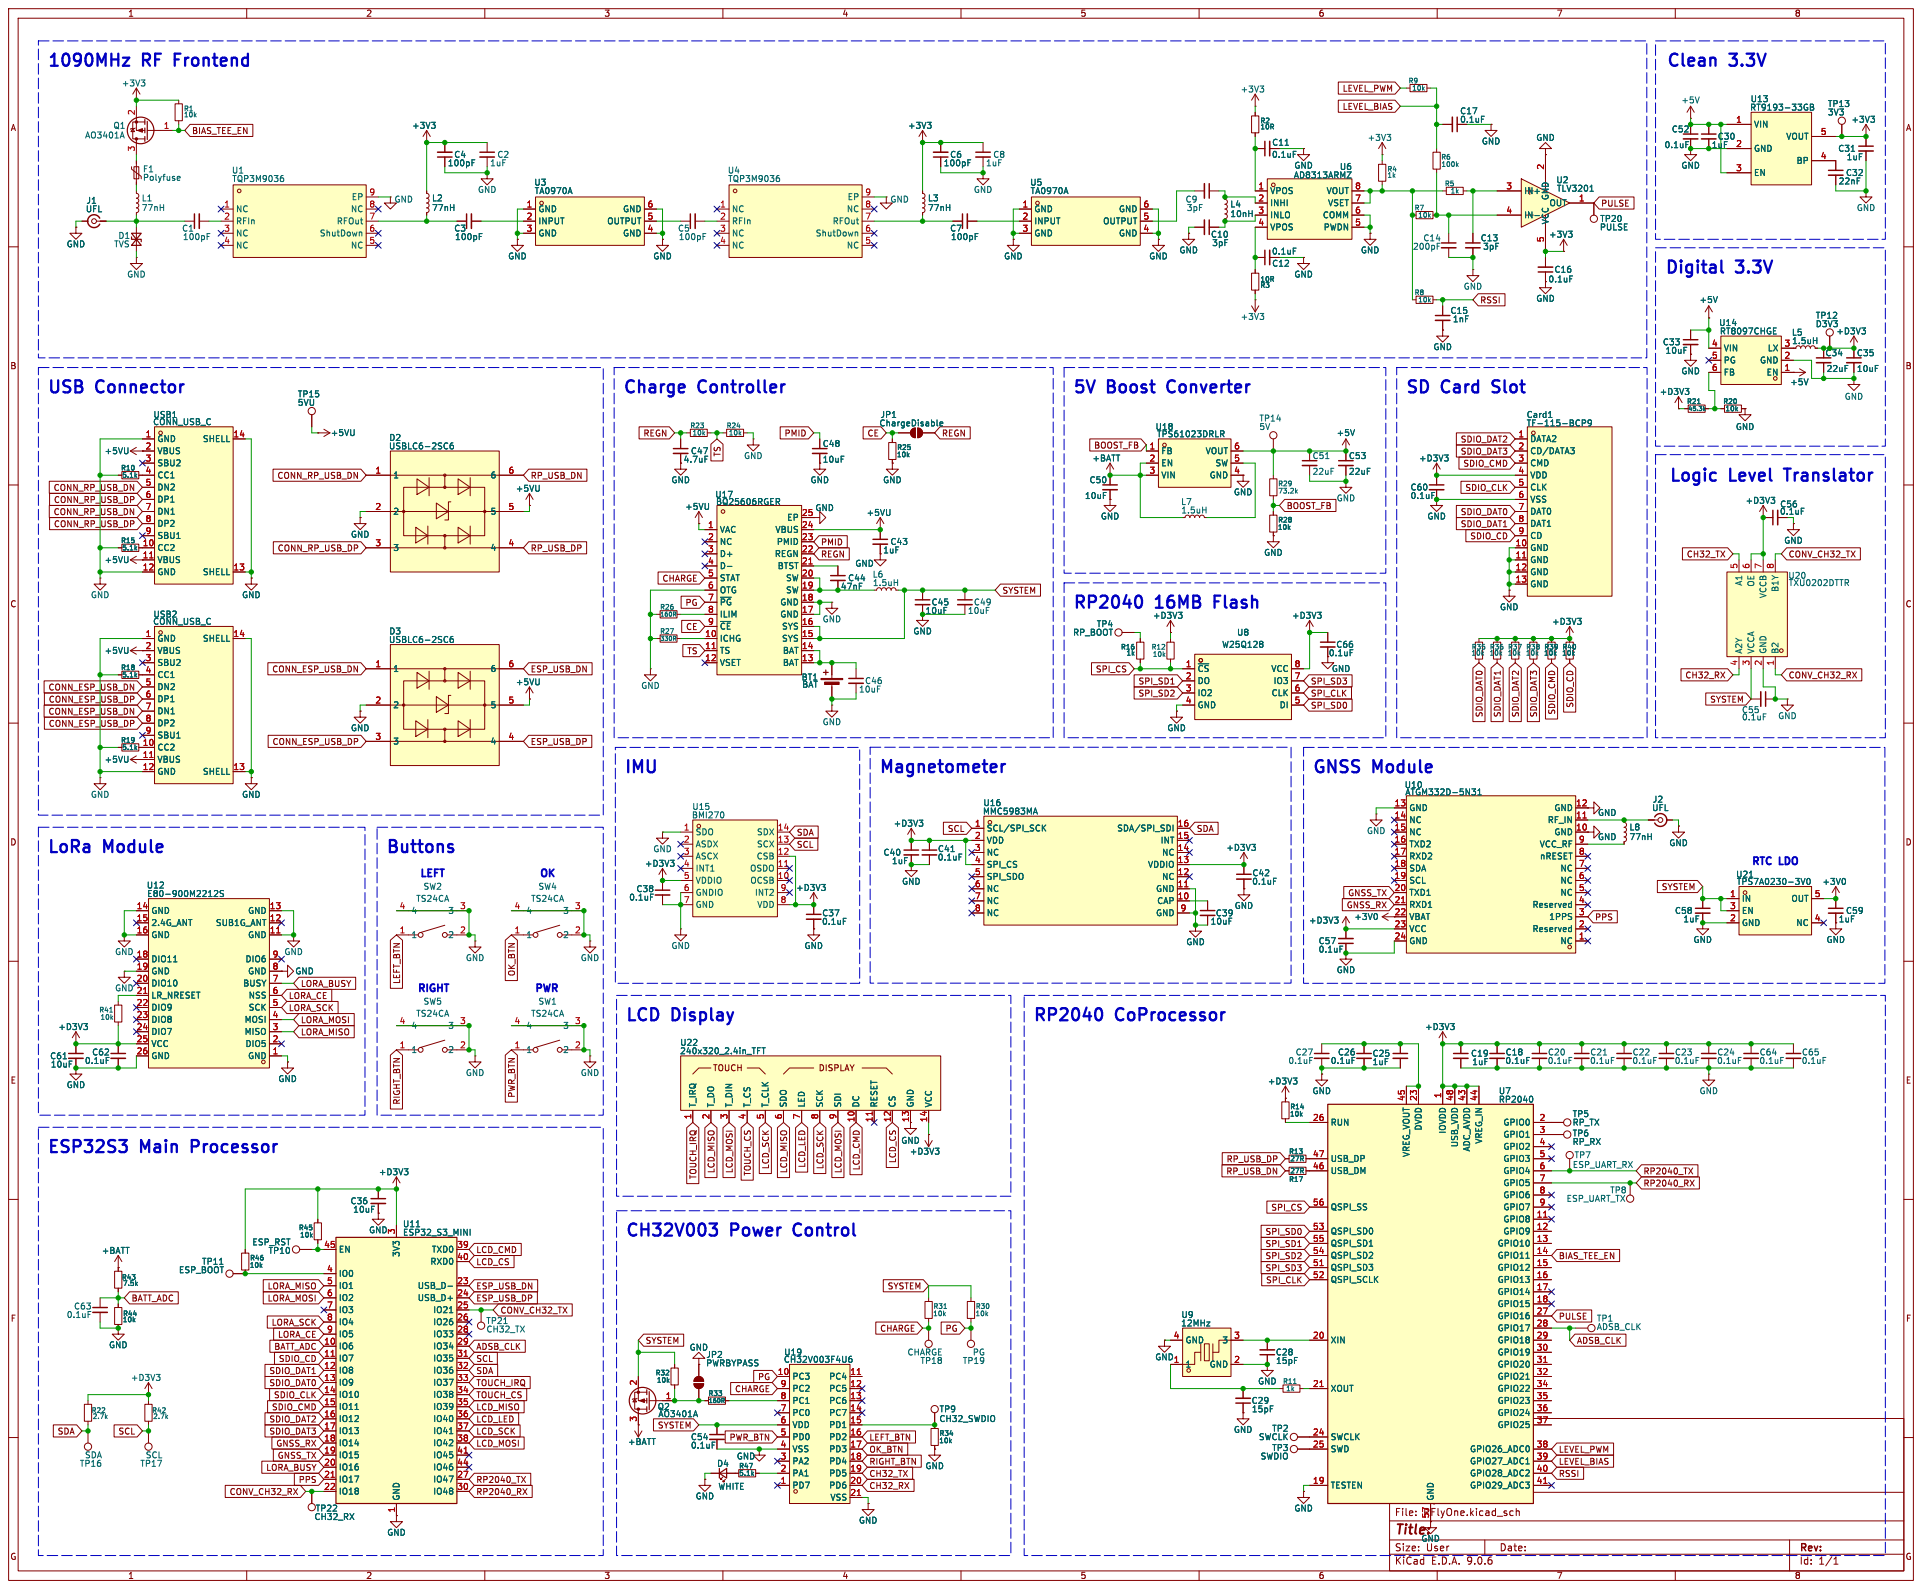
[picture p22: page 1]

2 OUT 1 U2TLV3201 GND GND GND GND

10k +D3V3 DATA2 1 CD/DATA3 2 CMD 3 VDD 4 CLK 5 VSS 6 DAT0 7 DAT1 8 CD 9 GND 10 GND 11 GND 12 GND 13 Card1 TF-115-BCP9 C1

BT1 BAT GND 1 DIO5 2 MISO 3 MOSI 4 SCK 5 NSS 6 BUSY 7 GND 8 DIO6 9 GND 11 GND 13 GND 26 VCC 25 DIO7 24 DIO8 23 DIO9 22

nRESET 8 NC 7 NC 6 NC 5 Reserved 4

8 SDI 9 DC 10 RESET 11 CS 12 GND 13 VCC 14 GND

8 SDI 9 DC 10 RESET 11 CS 12 GND 13 VCC 14 U22
240x320_2.4in_TFT

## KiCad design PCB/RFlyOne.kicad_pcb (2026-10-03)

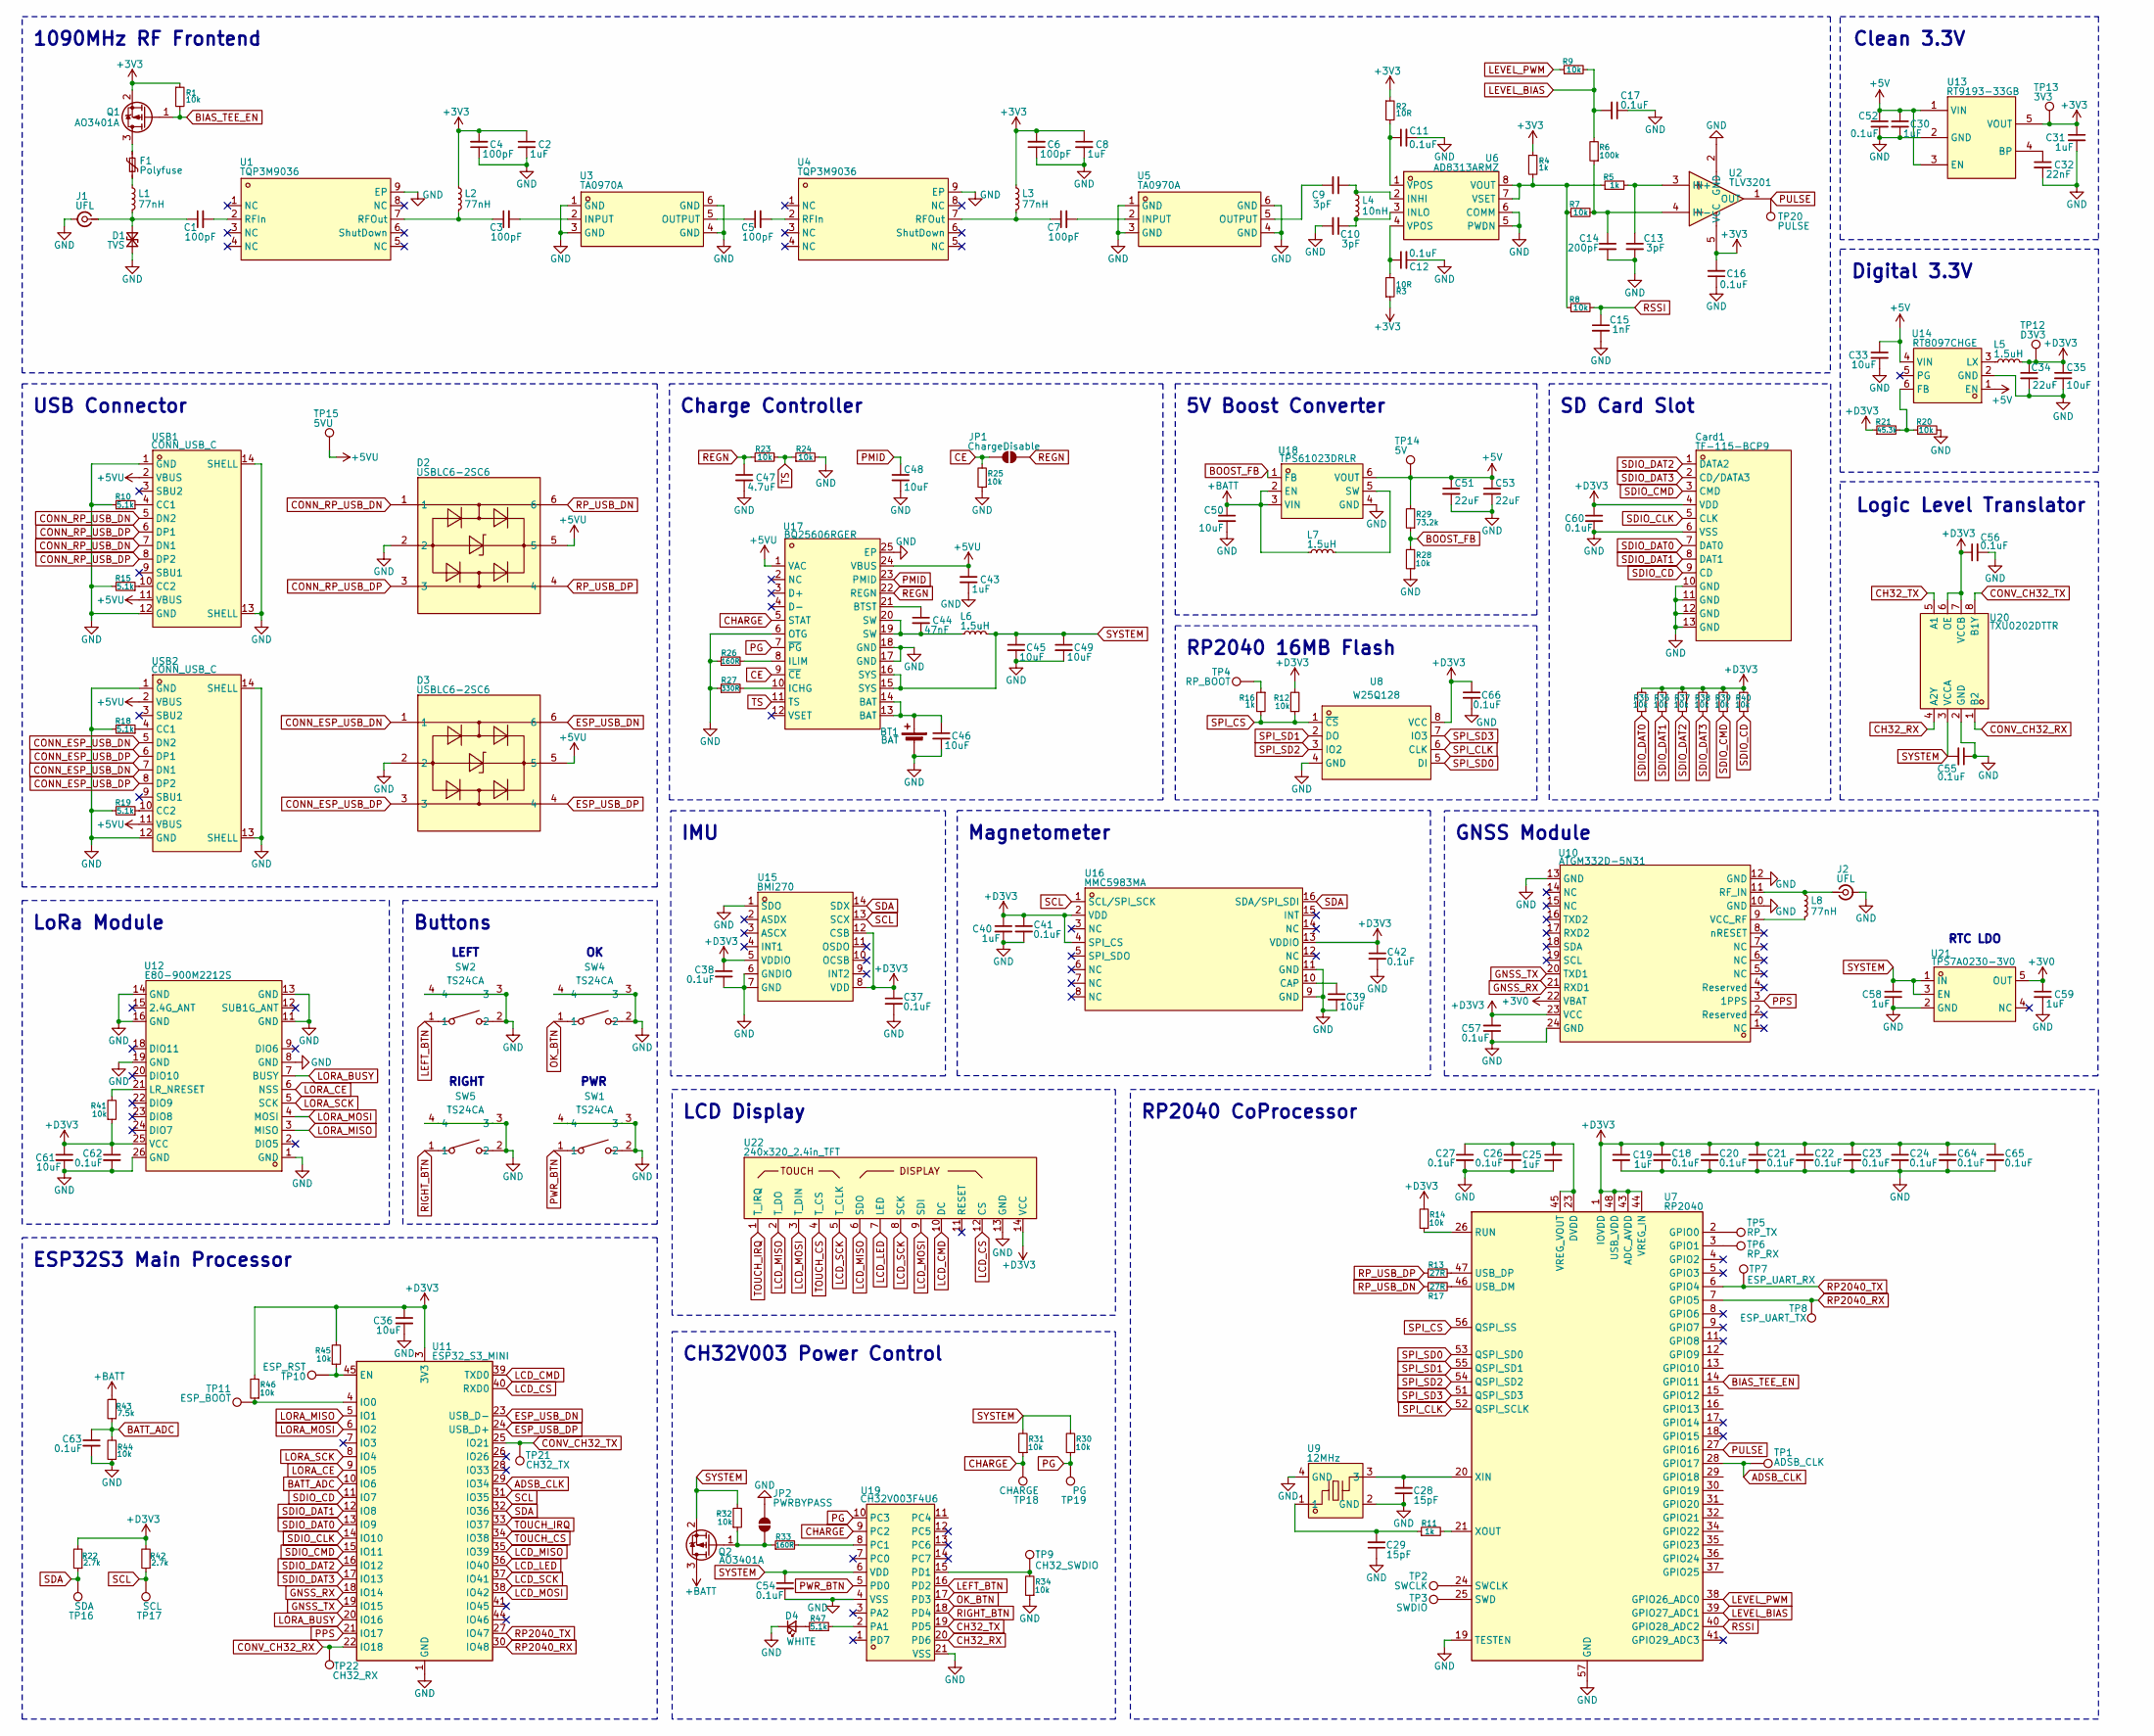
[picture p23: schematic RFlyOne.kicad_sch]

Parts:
BT1: BAT; Battery
C1, C3, C4, C5, C6, C7: 100pF; C_0402_1005Metric; LCSC Part C77177
C2, C8, C19, C25, C30, C31, C40, C43, C58, C59: 1uF; C_0402_1005Metric; LCSC Part C52923
C9, C10, C13: 3pF; C_0402_1005Metric; LCSC Part C88891
C11, C12, C16, C17, C18, C20, C21, C22, C23, C24, C26, C27, C37, C38, C41, C42, C52, C54, C55, C56, C57, C60, C62, C63, C64, C65, C66: 0.1uF; C_0402_1005Metric; LCSC Part C307331
C14: 200pF; C_0402_1005Metric; LCSC Part C325462
C15: 1nF; C_0402_1005Metric; LCSC Part C106205
C28, C29: 15pF; C_0402_1005Metric; LCSC Part C106997
C32: 22nF; C_0402_1005Metric; LCSC Part C1532
C33, C35, C36, C39, C45, C46, C48, C49, C50, C61: 10uF; C_0603_1608Metric; LCSC Part C96446
C34: 22uF; C_0603_1608Metric; LCSC Part C59461
C44: 47nF; C_0402_1005Metric; LCSC Part C272875
C47: 4.7uF; C_0402_1005Metric; LCSC Part C23733
C51, C53: 22uF; C_0805_2012Metric; LCSC Part C98190
Card1: TF-115-BCP9; TF-SMD_TF-115-BCP9; MPN TF-115-BCP9; LCSC Part C720505
D1: TVS; DFN-2_L1.0-W0.6-P0.65-BI; LCSC Part C22464622
D2, D3: USBLC6-2SC6; SOT-23-6_L2.9-W1.6-P0.95-LS2.8-BL; MPN USBLC6-2SC6; LCSC Part C7519
D4: WHITE; LED-SMD_L1.6-W1.1-R-RD_WHITE; LCSC Part C46635136
F1: Polyfuse; R_0402_1005Metric; LCSC Part C53280164
J1, J2: UFL; LCSC Part C5137195
JP1: ChargeDisable; SolderJumper-2_P1.3mm_Open_RoundedPad1.0x1.5mm
JP2: PWRBYPASS; SolderJumper-2_P1.3mm_Open_RoundedPad1.0x1.5mm
L1, L2, L3, L8: 77nH; L_0402_1005Metric; LCSC Part C668466
L4: 10nH; L_0402_1005Metric; LCSC Part C77103
L5, L6, L7: 1.5uH; L_Changjiang_FTC201610S; LCSC Part C5832343
Q1, Q2: AO3401A; SOT-23; LCSC Part C15127
R1, R7, R8, R9, R12, R14, R20, R23, R24, R25, R28, R30, R31, R32, R34, R35, R36, R37, R38, R39, R40, R41, R44, R45, R46: 10k; R_0402_1005Metric; LCSC Part C25744
R2, R3: 10R; R_0402_1005Metric; LCSC Part C25077
R4, R5, R11, R16: 1k; R_0402_1005Metric; LCSC Part C11702
R6: 100k; R_0402_1005Metric; LCSC Part C25741
R10, R15, R18, R19, R47: 5.1k; R_0402_1005Metric; LCSC Part C25905
R13, R17: 27R; R_0402_1005Metric; LCSC Part C138021
R21: 45.3k; R_0402_1005Metric; LCSC Part C137977
R22, R42: 2.7k; R_0402_1005Metric; LCSC Part C2909332
R26, R33: 160R; R_0402_1005Metric; LCSC Part C2933075
R27: 330R; R_0402_1005Metric; LCSC Part C2930002
R29: 73.2k; R_0402_1005Metric; LCSC Part C2998163
R43: 7.5k; R_0402_1005Metric; LCSC Part C25918
SW1, SW2, SW4, SW5: TS24CA; SW-SMD_2P-TS24CA; MPN TS24CA; LCSC Part C393942
TP1: ADSB_CLK; TestPoint
TP2: SWCLK; TestPoint
TP3: SWDIO; TestPoint
TP4: RP_BOOT; TestPoint
TP5: RP_TX; TestPoint
TP6: RP_RX; TestPoint
TP7: ESP_UART_RX; TestPoint
TP8: ESP_UART_TX; TestPoint
TP9: CH32_SWDIO; TestPoint
TP10: ESP_RST; TestPoint
TP11: ESP_BOOT; TestPoint
TP12: D3V3; TestPoint
TP13: 3V3; TestPoint
TP14: 5V; TestPoint
TP15: 5VU; TestPoint
TP16: SDA; TestPoint
TP17: SCL; TestPoint
TP18: CHARGE; TestPoint
TP19: PG; TestPoint
TP20: PULSE; TestPoint
TP21: CH32_TX; TestPoint
TP22: CH32_RX; TestPoint
U1, U4: TQP3M9036; DFN-8_L2.0-W2.0-P0.50-BL-EP; MPN TQP3M9036; LCSC Part C920261
U2: TLV3201; SOT-23-5_L3.0-W1.7-P0.95-LS2.8-BR; MPN TLV3201AIDBVR; LCSC Part C105188
U3, U5: TA0970A; FILTER-SMD_6P-L3.8-W3.8-BL; MPN TA0970A; LCSC Part C7115531
U6: AD8313ARMZ; MSOP-8_L3.0-W3.0-P0.65-LS4.9-BL; MPN AD8313ARMZ; LCSC Part C578690
U7: RP2040; QFN-56-1EP_7x7mm_P0.4mm_EP3.2x3.2mm; LCSC Part C2040
U8: W25Q128; SOIC-8_L5.3-W5.3-P1.27-LS8.0-BL; MPN W25Q128JVSIQ; LCSC Part C97521
U9: 12MHz; CRYSTAL-SMD_4P-L3.2-W2.5-BL; MPN ABM8-272-T3; LCSC Part C20625731
U10: ATGM332D-5N31; GSM-SMD_ATGM332D-5N31; MPN ATGM332D-5N31; LCSC Part C128659
U11: ESP32_S3_MINI; ESP32-S2-MINI-1U; LCSC Part C22356044
U12: E80-900M2212S; WIRELM-SMD_E80-900M2212S; MPN E80-900M2212S; LCSC Part C55338904
U13: RT9193-33GB; SOT-23-5_L3.0-W1.7-P0.95-LS2.8-BL; MPN RT9193-33GB; LCSC Part C15651
U14: RT8097CHGE; SOT-23-6_L2.9-W1.6-P0.95-LS2.8-BL; MPN RT8097CHGE; LCSC Part C3031673
U15: BMI270; LGA-14_L3.0-W2.5-P0.50-BR; MPN BMI270; LCSC Part C2836813
U16: MMC5983MA; LGA-16_L3.0-W3.0-P0.50-BL_SQ; MPN MMC5983MA; LCSC Part C404329
U17: BQ25606RGER; VQFN-24_L4.0-W4.0-P0.50-TL-EP2.8; MPN BQ25606RGER; LCSC Part C374063
U18: TPS61023DRLR; SOT-563_L1.6-W1.2-P0.50-LS1.6-BR; MPN TPS61023DRLR; LCSC Part C919459
U19: CH32V003F4U6; QFN-20_L3.0-W3.0-P0.40-TL-EP1.7; MPN CH32V003F4U6; LCSC Part C5299908
U20: TXU0202DTTR; XSON-8_L2.0-W1.0-P0.50-BL; MPN TXU0202DTTR; LCSC Part C18197534
U21: TPS7A0230-3V0; SOT-23-5_L2.9-W1.6-P0.95-LS2.8-BR; MPN TPS7A0230PDBVR; LCSC Part C3747031
U22: 240x320_2.4in_TFT; 2.4TFT
USB1, USB2: CONN_USB_C; USB-C-SMD_TYPE-C-6PIN-2MD-073; LCSC Part C2765186

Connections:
+3V0: C59.1, U10.22 (VBAT), U21.5 (OUT)
+3V3: C2.1, C4.2, C6.2, C8.1, C16.2, C31.1, L2.1, L3.1, Q1.2 (S), R1.1, R2.1, R3.1, R4.1, TP13.1, U2.5 (VCC), U13.5 (VOUT)
+5V: C30.1, C33.1, C51.1, C52.1, C53.1, R29.2, TP14.1, U13.1 (VIN), U13.3 (EN), U14.1 (EN), U14.4 (VIN), U18.6 (VOUT)
+5VU: C43.1, D2.5, D3.5, TP15.1, U17.1 (VAC), U17.24 (VBUS), USB1.2 (VBUS), USB1.11 (VBUS), USB2.2 (VBUS), USB2.11 (VBUS)
+BATT: C50.1, L7.1, Q2.3 (D), R43.2, U18.2 (EN), U18.3 (VIN)
+D3V3: C18.1, C19.1, C20.1, C21.1, C22.1, C23.1, C24.1, C34.1, C35.1, C36.1, C37.1, C38.1, C40.1, C41.1, C42.1, C56.1, C57.2, C60.1, C61.1, C62.1, C64.1, C65.1, C66.1, Card1.4 (VDD), L5.2, R12.2, R14.2, R21.1, R22.2, R35.2, R36.2, R37.2, R38.2, R39.2, R40.2, R41.1, R42.2, R45.2, R46.2, TP12.1, U7.1 (IOVDD), U7.10 (IOVDD), U7.22 (IOVDD), U7.33 (IOVDD), U7.42 (IOVDD), U7.43 (ADC_AVDD), U7.44 (VREG_IN), U7.48 (USB_VDD), U7.49 (IOVDD), U8.8 (VCC), U10.23 (VCC), U11.3 (3V3), U12.25 (VCC), U15.5 (VDDIO), U15.8 (VDD), U15.12 (CSB), U16.2 (VDD), U16.4 (SPI_CS), U16.13 (VDDIO), U20.6 (OE), U20.7 (VCCB), U22.14 (VCC)
ADSB_CLK: TP1.1, U7.28 (GPIO17), U11.29 (IO34)
BATT_ADC: C63.1, R43.1, R44.2, U11.10 (IO6)
BIAS_TEE_EN: Q1.1 (G), R1.2, U7.14 (GPIO11)
BOOST_FB: R28.2, R29.1, U18.1 (FB)
CE: JP1.1 (A), R25.2, U17.9 (~CE)
CH32_RX: U19.20 (PD6), U20.4 (A2Y)
CH32_TX: U19.19 (PD5), U20.5 (A1)
CHARGE: R31.1, TP18.1, U17.5 (STAT), U19.9 (PC2)
CONN_ESP_USB_DN: D3.1, USB2.5 (DN2), USB2.7 (DN1)
CONN_ESP_USB_DP: D3.3, USB2.6 (DP1), USB2.8 (DP2)
CONN_RP_USB_DN: D2.1, USB1.5 (DN2), USB1.7 (DN1)
CONN_RP_USB_DP: D2.3, USB1.6 (DP1), USB1.8 (DP2)
CONV_CH32_RX: TP22.1, U11.22 (IO18), U20.1 (B2)
CONV_CH32_TX: TP21.1, U11.25 (IO21), U20.8 (B1Y)
ESP_USB_DN: D3.6, U11.23 (USB_D-)
ESP_USB_DP: D3.4, U11.24 (USB_D+)
GND: BT1.2 (-), C2.2, C4.1, C6.1, C8.2, C10.2, C11.2, C12.2, C13.2, C14.2, C15.2, C16.1, C17.1, C18.2, C19.2, C20.2, C21.2, C22.2, C23.2, C24.2, C25.2, C26.2, C27.2, C28.1, C29.1, C30.2, C31.2, C32.2, C33.2, C34.2, C35.2, C36.2, C37.2, C38.2, C39.2, C40.2, C41.2, C42.2, C43.2, C45.2, C46.2, C47.2, C48.2, C49.2, C50.2, C51.2, C52.2, C53.2, C54.2, C55.1, C56.2, C57.1, C58.2, C59.2, C60.2, C61.2, C62.2, C63.2, C64.2, C65.2, C66.2, Card1.6 (VSS), Card1.10 (GND), Card1.11 (GND), Card1.12 (GND), Card1.13 (GND), D1.1 (A1), D2.2, D3.2, D4.1 (K), J1.2 (Ext), J2.2 (Ext), JP2.2 (B), R10.2, R15.2, R18.2, R19.2, R20.2, R24.2, R25.1, R26.1, R27.1, R28.1, R34.1, R44.1, SW1.2, SW1.3, SW1.4, SW2.2, SW2.3, SW2.4, SW4.2, SW4.3, SW4.4, SW5.2, SW5.3, SW5.4, U1.9 (EP), U2.2 (GND), U3.1 (GND), U3.3 (GND), U3.4 (GND), U3.6 (GND), U4.9 (EP), U5.1 (GND), U5.3 (GND), U5.4 (GND), U5.6 (GND), U6.5 (PWDN), U6.6 (COMM), U7.19 (TESTEN), U7.57 (GND), U8.4 (GND), U9.2 (GND), U9.4 (GND), U10.10 (GND), U10.12 (GND), U10.13 (GND), U10.24 (GND), U11.1 (GND), U11.2 (GND), U11.42 (GND), U11.43 (GND), U11.46 (GND), U11.47 (GND), U11.48 (GND), U11.49 (GND), U11.50 (GND), U11.51 (GND), U11.52 (GND), U11.53 (GND), U11.54 (GND), U11.55 (GND), U11.56 (GND), U11.57 (GND), U11.58 (GND), U11.59 (GND), U11.60 (GND), U11.61 (GND), U11.62 (GND), U11.63 (GND), U11.64 (GND), U11.65 (GND), U12.1 (GND), U12.8 (GND), U12.11 (GND), U12.13 (GND), U12.14 (GND), U12.16 (GND), U12.19 (GND), U12.26 (GND), U13.2 (GND), U14.2 (GND), U15.1 (SDO), U15.6 (GNDIO), U15.7 (GND), U16.9 (GND), U16.11 (GND), U17.6 (OTG), U17.17 (GND), U17.18 (GND), U17.25 (EP), U18.4 (GND), U19.4 (VSS), U19.21 (VSS), U20.2 (GND), U21.2 (GND), U22.13 (GND), USB1.1 (GND), USB1.12 (GND), USB1.13 (SHELL), USB1.14 (SHELL), USB2.1 (GND), USB2.12 (GND), USB2.13 (SHELL), USB2.14 (SHELL)
GNSS_RX: U10.21 (RXD1), U11.18 (IO14)
GNSS_TX: U10.20 (TXD1), U11.19 (IO15)
LCD_CMD: U11.39 (TXD0), U22.10 (DC)
LCD_CS: U11.40 (RXD0), U22.12 (CS)
LCD_LED: U11.36 (IO40), U22.7 (LED)
LCD_MISO: U11.35 (IO39), U22.2 (T_DO), U22.6 (SDO)
LCD_MOSI: U11.38 (IO42), U22.3 (T_DIN), U22.9 (SDI)
LCD_SCK: U11.37 (IO41), U22.5 (T_CLK), U22.8 (SCK)
LEFT_BTN: SW2.1, U19.16 (PD2)
LEVEL_BIAS: C17.2, R6.2, R9.2, U7.39 (GPIO27_ADC1)
LEVEL_PWM: R9.1, U7.38 (GPIO26_ADC0)
LORA_BUSY: U11.20 (IO16), U12.7 (BUSY)
LORA_CE: U11.9 (IO5), U12.6 (NSS)
LORA_MISO: U11.5 (IO1), U12.3 (MISO)
LORA_MOSI: U11.6 (IO2), U12.4 (MOSI)
LORA_SCK: U11.8 (IO4), U12.5 (SCK)
unnamed: BT1.1 (+), C46.1, U17.13 (BAT), U17.14 (BAT)
unnamed: C11.1, R2.2, U6.1 (VPOS)
unnamed: C12.1, R3.2, U6.4 (VPOS)
unnamed: C29.2, R11.1, U9.1
unnamed: C44.2, L6.1, U17.19 (SW), U17.20 (SW)
unnamed: C1.1, D1.2 (A2), J1.1 (In), L1.2
unnamed: D4.2 (A), R47.2
unnamed: F1.2, L1.1
unnamed: J2.1 (In), L8.1, U10.11 (RF_IN)
unnamed: JP2.1 (A), Q2.1 (G), R32.1, R33.1
unnamed: F1.1, Q1.3 (D)
unnamed: R16.1, TP4.1
unnamed: C1.2, U1.2 (RFIn)
unnamed: C3.1, L2.2, U1.7 (RFOut)
unnamed: C13.1, R5.2, U2.3 (IN+)
unnamed: C14.1, R6.1, R7.2, U2.4 (IN-)
unnamed: C3.2, U3.2 (INPUT)
unnamed: C5.1, U3.5 (OUTPUT)
unnamed: C5.2, U4.2 (RFIn)
unnamed: C7.1, L3.2, U4.7 (RFOut)
unnamed: C7.2, U5.2 (INPUT)
unnamed: C9.2, U5.5 (OUTPUT)
unnamed: C9.1, L4.1, U6.2 (INHI)
unnamed: C10.1, L4.2, U6.3 (INLO)
unnamed: R4.2, R5.1, R7.1, R8.1, U6.7 (VSET), U6.8 (VOUT)
unnamed: TP5.1, U7.2 (GPIO0)
unnamed: TP6.1, U7.3 (GPIO1)
unnamed: R14.1, U7.26 (RUN)
unnamed: TP2.1, U7.24 (SWCLK)
unnamed: TP3.1, U7.25 (SWD)
unnamed: R17.2, U7.46 (USB_DM)
unnamed: R13.2, U7.47 (USB_DP)
unnamed: C25.1, C26.1, C27.1, U7.23 (DVDD), U7.45 (VREG_VOUT), U7.50 (DVDD)
unnamed: C28.2, U7.20 (XIN), U9.3
unnamed: R11.2, U7.21 (XOUT)
unnamed: L8.2, U10.9 (VCC_RF)
unnamed: R45.1, TP10.1, U11.45 (EN)
unnamed: R46.1, TP11.1, U11.4 (IO0)
unnamed: R41.2, U12.21 (LR_NRESET)
unnamed: C32.1, U13.4 (BP)
unnamed: R20.1, R21.2, U14.6 (FB)
unnamed: L5.1, U14.3 (LX)
unnamed: C39.1, U16.10 (CAP)
unnamed: C44.1, U17.21 (BTST)
unnamed: R27.2, U17.10 (ICHG)
unnamed: R26.2, U17.8 (ILIM)
unnamed: L7.2, U18.5 (SW)
unnamed: R47.1, U19.2 (PA1)
unnamed: R33.2, U19.8 (PC1)
unnamed: R34.2, TP9.1, U19.15 (PD1)
unnamed: R10.1, USB1.4 (CC1)
unnamed: R15.1, USB1.10 (CC2)
unnamed: R18.1, USB2.4 (CC1)
unnamed: R19.1, USB2.10 (CC2)
OK_BTN: SW4.1, U19.17 (PD3)
PG: R30.1, TP19.1, U17.7 (~PG), U19.10 (PC3)
PMID: C48.1, U17.23 (PMID)
PPS: U10.3 (1PPS), U11.21 (IO17)
PULSE: TP20.1, U2.1 (OUT), U7.27 (GPIO16)
PWR_BTN: SW1.1, U19.5 (PD0)
REGN: C47.1, JP1.2 (B), R23.1, U17.22 (REGN)
RIGHT_BTN: SW5.1, U19.18 (PD4)
RP2040_RX: TP8.1, U7.7 (GPIO5), U11.30 (IO48)
RP2040_TX: TP7.1, U7.6 (GPIO4), U11.27 (IO47)
RP_USB_DN: D2.6, R17.1
RP_USB_DP: D2.4, R13.1
RSSI: C15.1, R8.2, U7.40 (GPIO28_ADC2)
SCL: R42.1, TP17.1, U11.31 (IO35), U15.13 (SCX), U16.1 (SCL/SPI_SCK)
SDA: R22.1, TP16.1, U11.32 (IO36), U15.14 (SDX), U16.16 (SDA/SPI_SDI)
SDIO_CD: Card1.9 (CD), R40.1, U11.11 (IO7)
SDIO_CLK: Card1.5 (CLK), U11.14 (IO10)
SDIO_CMD: Card1.3 (CMD), R39.1, U11.15 (IO11)
SDIO_DAT0: Card1.7 (DAT0), R35.1, U11.13 (IO9)
SDIO_DAT1: Card1.8 (DAT1), R36.1, U11.12 (IO8)
SDIO_DAT2: Card1.1 (DATA2), R37.1, U11.16 (IO12)
SDIO_DAT3: Card1.2 (CD/DATA3), R38.1, U11.17 (IO13)
SPI_CLK: U7.52 (QSPI_SCLK), U8.6 (CLK)
SPI_CS: R12.1, R16.2, U7.56 (QSPI_SS), U8.1 (~CS)
SPI_SD0: U7.53 (QSPI_SD0), U8.5 (DI)
SPI_SD1: U7.55 (QSPI_SD1), U8.2 (DO)
SPI_SD2: U7.54 (QSPI_SD2), U8.3 (IO2)
SPI_SD3: U7.51 (QSPI_SD3), U8.7 (IO3)
SYSTEM: C45.1, C49.1, C54.1, C55.2, C58.1, L6.2, Q2.2 (S), R30.2, R31.2, R32.2, U17.15 (SYS), U17.16 (SYS), U19.6 (VDD), U20.3 (VCCA), U21.1 (IN), U21.3 (EN)
TOUCH_CS: U11.34 (IO38), U22.4 (T_CS)
TOUCH_IRQ: U11.33 (IO37), U22.1 (T_IRQ)
TS: R23.2, R24.1, U17.11 (TS)

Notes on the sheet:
1090MHz RF Frontend
Buttons
RP2040 16MB Flash
RIGHT
LCD Display
Digital 3.3V
RTC LDO
Logic Level Translator
Charge Controller
Clean 3.3V
GNSS Module
PWR
LEFT
Magnetometer
LoRa Module
SD Card Slot
USB Connector
IMU
RP2040 CoProcessor
ESP32S3 Main Processor
5V Boost Converter
CH32V003 Power Control

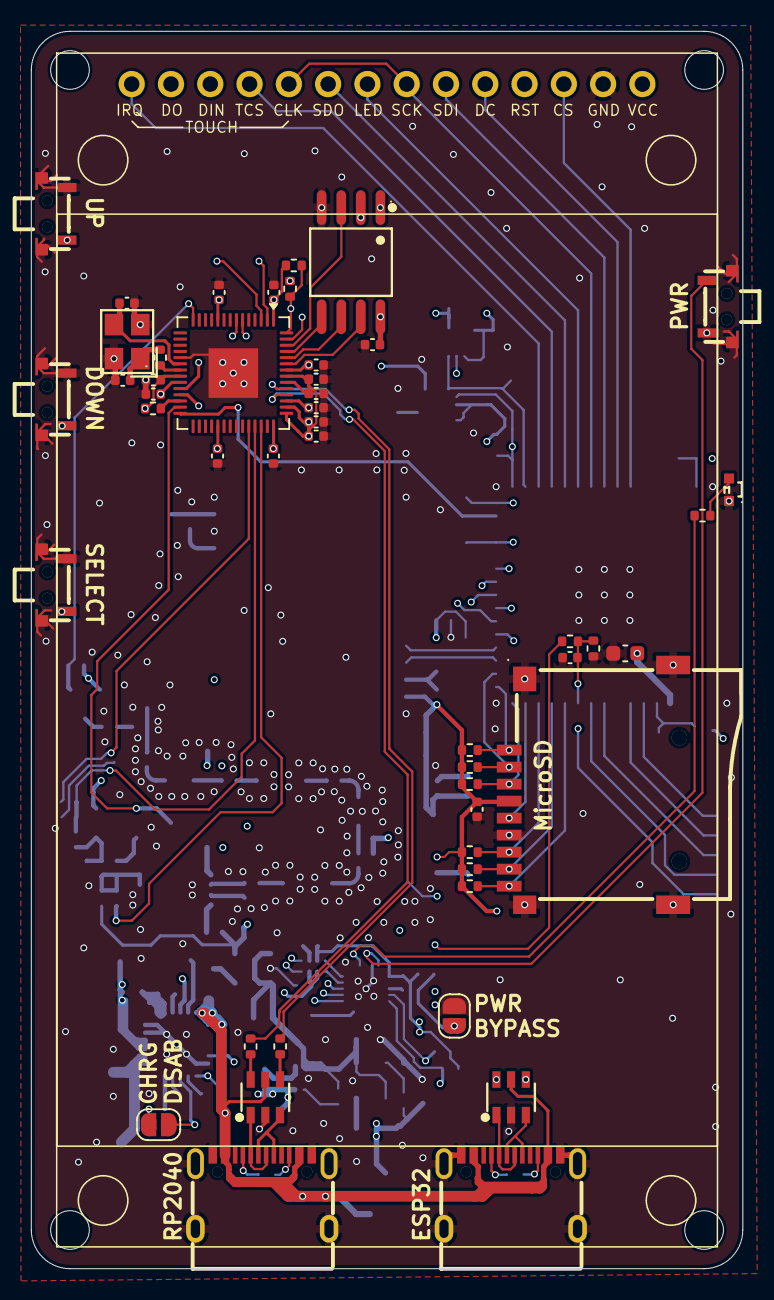
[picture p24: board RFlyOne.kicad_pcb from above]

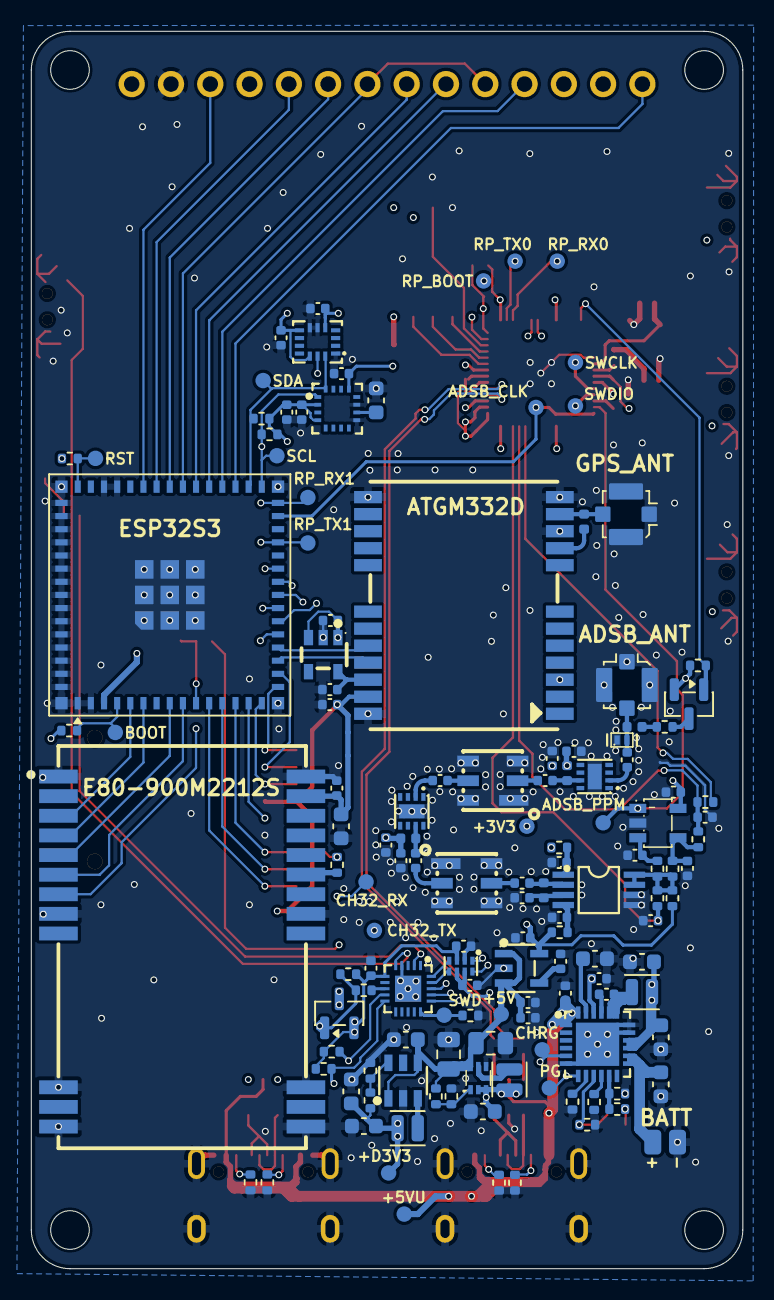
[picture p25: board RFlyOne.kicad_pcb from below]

Board: 4 copper layers, 46.0 x 80.0 mm, 184 parts (135 on the bottom side), 125 nets.

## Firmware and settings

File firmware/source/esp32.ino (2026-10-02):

// Written with Gemini. Firmware time not counted.
#include <Arduino.h>
#include <SPI.h>
#include <Wire.h>
#include <Adafruit_GFX.h>
#include <Adafruit_ILI9341.h>
#include <Adafruit_BMI270.h>
#include <Adafruit_MMC5983.h>
#include <SD_MMC.h>
#include <RadioLib.h>

// --- Pin Definitions ---
// TFT LCD
#define LCD_MOSI   42
#define LCD_MISO   39
#define LCD_SCK    41
#define LCD_CMD    43
#define LCD_CS     44
#define LCD_LED    40

// I2C
#define I2C_SDA    36
#define I2C_SCL    35

// SDIO SD Card
#define SDIO_DAT0  9
#define SDIO_DAT1  8
#define SDIO_DAT2  12
#define SDIO_DAT3  13
#define SDIO_CMD   11
#define SDIO_CLK   10
#define SDIO_CD    7

// LoRa (LR2021 / LR1121)
#define LORA_BUSY  16
#define LORA_CE    5
#define LORA_SCK   4
#define LORA_MOSI  2
#define LORA_MISO  1

// GNSS
#define GNSS_TX_ESP_RX  15
#define GNSS_RX_ESP_TX  14
#define GNSS_PPS        17

// Coprocessors & ADSB
#define CH32_RX_PIN     21 // ESP RX
#define CH32_TX_PIN     18 // ESP TX
#define RP2040_RX_PIN   47 // ESP RX
#define RP2040_TX_PIN   48 // ESP TX
#define ADSB_CLK        34

// --- Peripherals & Objects ---
SPIClass tftSPI(FSPI);
Adafruit_ILI9341 tft = Adafruit_ILI9341(&tftSPI, LCD_CMD, LCD_CS, -1);

SPIClass loraSPI(HSPI);
LR1121 radio = new Module(LORA_CE, RADIOLIB_NC, RADIOLIB_NC, LORA_BUSY, loraSPI);

Adafruit_BMI270 bmi;
Adafruit_MMC5983MA mmc;

// Hardware UARTS (ESP32-S3 has 3: Serial0, Serial1, Serial2)
// Assumes USB CDC is enabled for the main `Serial` monitor.
HardwareSerial SerialRP(0);   
HardwareSerial SerialGNSS(1); 
HardwareSerial SerialCH(2);   

// --- Global State ---
bool sdOk = false;
bool loraOk = false;
bool bmiOk = false;
bool mmcOk = false;

volatile uint32_t adsb_pulse_count = 0;
uint32_t last_adsb_count = 0;
uint32_t last_update_ms = 0;

// ADSB Clock Interrupt
void IRAM_ATTR adsb_isr() {
    adsb_pulse_count++;
}

void setup() {
    Serial.begin(115200);

    // 1. Initialize TFT
    pinMode(LCD_LED, OUTPUT);
    digitalWrite(LCD_LED, HIGH); // Turn on backlight
    tftSPI.begin(LCD_SCK, LCD_MISO, LCD_MOSI, LCD_CS);
    tft.begin();
    tft.setRotation(3); // Landscape
    tft.fillScreen(ILI9341_BLACK);
    tft.setTextColor(ILI9341_WHITE, ILI9341_BLACK);
    tft.setTextSize(2);
    tft.setCursor(0, 0);
    tft.println("Initializing System...");

    // 2. Initialize I2C & Sensors
    Wire.begin(I2C_SDA, I2C_SCL);
    bmiOk = bmi.begin(0x68, &Wire);
    mmcOk = mmc.begin();

    // 3. Initialize SDIO SD Card
    pinMode(SDIO_CD, INPUT_PULLUP);
    SD_MMC.setPins(SDIO_CLK, SDIO_CMD, SDIO_DAT0, SDIO_DAT1, SDIO_DAT2, SDIO_DAT3);
    if (digitalRead(SDIO_CD) == LOW) { // Card Detected
        sdOk = SD_MMC.begin();
    }

    // 4. Initialize LoRa
    loraSPI.begin(LORA_SCK, LORA_MISO, LORA_MOSI, LORA_CE);
    int state = radio.begin();
    loraOk = (state == RADIOLIB_ERR_NONE);

    // 5. Initialize UARTS
    SerialGNSS.begin(9600, SERIAL_8N1, GNSS_TX_ESP_RX, GNSS_RX_ESP_TX);
    SerialCH.begin(115200, SERIAL_8N1, CH32_RX_PIN, CH32_TX_PIN);
    SerialRP.begin(115200, SERIAL_8N1, RP2040_RX_PIN, RP2040_TX_PIN);

    // 6. Initialize ADSB Clock Interrupt
    pinMode(ADSB_CLK, INPUT);
    attachInterrupt(digitalPinToInterrupt(ADSB_CLK), adsb_isr, RISING);
}

void loop() {
    uint32_t now = millis();
    
    // Update screen and run checks every 500ms
    if (now - last_update_ms >= 500) {
        last_update_ms = now;
        
        tft.setCursor(0, 0);

        // --- I2C Sensors ---
        if (bmiOk) {
            sensors_event_t accel, gyro, temp;
            bmi.getEvent(&accel, &gyro, &temp);
            tft.printf("BMI: X:%.1f Y:%.1f  \n", accel.acceleration.x, accel.acceleration.y);
        } else {
            tft.println("BMI270: FAIL       ");
        }

        if (mmcOk) {
            sensors_event_t magEvent;
            mmc.getEvent(&magEvent);
            tft.printf("MMC: X:%.0f Y:%.0f  \n", magEvent.magnetic.x, magEvent.magnetic.y);
        } else {
            tft.println("MMC5983: FAIL      ");
        }

        // --- SD Card ---
        tft.printf("SD Card: %s \n", (sdOk && digitalRead(SDIO_CD) == LOW) ? "OK      " : "NOT MNT ");

        // --- LoRa ---
        tft.printf("LR2021: %s \n", loraOk ? "OK      " : "FAIL    ");

        // --- ADSB Clock ---
        uint32_t current_count = adsb_pulse_count;
        uint32_t hz = (current_count - last_adsb_count) * 2; // *2 because loop is 500ms
        last_adsb_count = current_count;
        tft.printf("ADSB CLK: %lu Hz   \n", hz);

        // --- GNSS ---
        bool gnssData = false;
        while (SerialGNSS.available()) {
            SerialGNSS.read(); // Flush buffer
            gnssData = true;
        }
        tft.printf("GNSS UART: %s \n", gnssData ? "ACTIVE  " : "WAITING ");

        // --- CH32V003 Coprocessor ---
        SerialCH.print("C"); // Send test char
        delay(10); // Brief wait for loopback
        bool ch32Ok = false;
        while (SerialCH.available()) {
            if (SerialCH.read() == 'C') ch32Ok = true;
        }
        tft.printf("CH32 UART: %s \n", ch32Ok ? "LOOP OK " : "FAIL    ");

        // --- RP2040 Coprocessor ---
        SerialRP.print("R"); // Send test char
        delay(10);
        bool rpOk = false;
        while (SerialRP.available()) {
            if (SerialRP.read() == 'R') rpOk = true;
        }
        tft.printf("RP20 UART: %s \n", rpOk ? "LOOP OK " : "FAIL    ");
    }
}

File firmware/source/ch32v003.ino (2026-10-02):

// Written with Gemini. Firmware time not counted.
// --- Pin Definitions ---
#define LED_PIN    PA1
#define MOSFET_PIN PC1

#define BTN_RIGHT  PD4
#define BTN_LEFT   PD2
#define BTN_OK     PD3
#define BTN_PWR    PD0

// --- Button Structure ---
struct Button {
  uint8_t pin;
  const char* name;
  bool state;
  bool lastReading;
  unsigned long lastDebounceTime;
};

// Initialize buttons (assuming default unpressed state is HIGH due to pull-ups)
Button buttons[4] = {
  {BTN_RIGHT, "RIGHT_BTN", HIGH, HIGH, 0},
  {BTN_LEFT,  "LEFT_BTN",  HIGH, HIGH, 0},
  {BTN_OK,    "OK_BTN",    HIGH, HIGH, 0},
  {BTN_PWR,   "PWR_BTN",   HIGH, HIGH, 0}
};

// --- State Variables ---
bool mosfetOn = false;        // MOSFET state track
bool ledState = LOW;          // LED state track
unsigned long lastBlink = 0;  // Blink timing

const unsigned long debounceDelay = 50; // 50ms debounce time

void setup() {
  // Initialize UART at 115200 baud (Defaults to PD5 TX, PD6 RX)
  Serial.begin(115200);

  // Initialize LED
  pinMode(LED_PIN, OUTPUT);

  // Initialize P-Channel MOSFET
  // PC1 goes LOW to turn on, so we initialize it to HIGH (OFF)
  pinMode(MOSFET_PIN, OUTPUT);
  digitalWrite(MOSFET_PIN, HIGH);

  // Initialize Buttons with internal pull-ups
  for (int i = 0; i < 4; i++) {
    pinMode(buttons[i].pin, INPUT_PULLUP);
    buttons[i].state = digitalRead(buttons[i].pin);
    buttons[i].lastReading = buttons[i].state;
  }
}

void loop() {
  unsigned long currentMillis = millis();

  // 1. Non-blocking LED Blink (Toggle every 500ms)
  if (currentMillis - lastBlink >= 500) {
    lastBlink = currentMillis;
    ledState = !ledState;
    digitalWrite(LED_PIN, ledState);
  }

  // 2. UART Message Relay (Echo RX to TX)
  while (Serial.available() > 0) {
    Serial.write(Serial.read());
  }

  // 3. Button Reading & Debouncing
  for (int i = 0; i < 4; i++) {
    bool reading = digitalRead(buttons[i].pin);

    // If the switch changed (due to noise or pressing)
    if (reading != buttons[i].lastReading) {
      buttons[i].lastDebounceTime = currentMillis;
    }

    // If the reading has been stable longer than the debounce delay
    if ((currentMillis - buttons[i].lastDebounceTime) > debounceDelay) {
      // If the actual button state has changed
      if (reading != buttons[i].state) {
        buttons[i].state = reading;

        // Send state change over UART
        Serial.print(buttons[i].name);
        Serial.print(" ");
        Serial.println(buttons[i].state); // 0 when pressed, 1 when released

        // 4. Special handling for PWR Button toggle logic
        // Check if this is the PWR button and it was just pressed (went LOW)
        if (buttons[i].pin == BTN_PWR && buttons[i].state == LOW) {
          mosfetOn = !mosfetOn;
          
          if (mosfetOn) {
            digitalWrite(MOSFET_PIN, LOW);  // Turn P-MOSFET ON
          } else {
            digitalWrite(MOSFET_PIN, HIGH); // Turn P-MOSFET OFF
          }
        }
      }
    }
    // Save the reading for the next loop comparison
    buttons[i].lastReading = reading;
  }
}
